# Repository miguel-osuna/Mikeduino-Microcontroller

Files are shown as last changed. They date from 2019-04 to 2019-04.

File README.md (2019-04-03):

# Mikeduino - My version of Arduino Uno R3
*"Mikeduino"* is a microcontroller board designed as a final project for the subject of Printed Circuits of the Electronics Engineering career.

## Purpose
It is based on the Open Source design of the *Arduino Uno R3* Microcontroller, but with the intention of improving the following aspects:

- Power signals
- Control signals
- Micro-USB port
- THT capacitor for improvement of power signal filtering

## Design 
The *Altium Designer 18* design software was used to create the following:

- Library of Components
- Bill Of Materials
- Schematic Diagram
- PCB design
- Generation of Documentation

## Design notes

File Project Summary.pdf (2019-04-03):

# Reporte de Proyecto Final

### Nombre del Circuito y Especificaciones Técnicas

### Alumno: Osuna Angulo Miguel Angel / 1237683 Nombre del Circuito: Mikeduino

Voltaje de operación | 5 V | SRAM | 2 KB
Voltaje de alimentación máximo: | 12 V | EEPROM | 1 KB
Pines Digitales de E/S | 14 | Velocidad de Reloj | 16 MHz
Pines Analógicos de Entrada | 6 | Largo (L) | 68.6 mm
Corriente máxima por pin (CD) | 40 mA | Ancho (W) | 54.5 mm
Memoria Flash | 32 KB ; para 0.5 KB bootloader | Peso | 25 g

### Tabla 1.- Especificaciones Técnicas del PCB

### Diagrama a Bloques

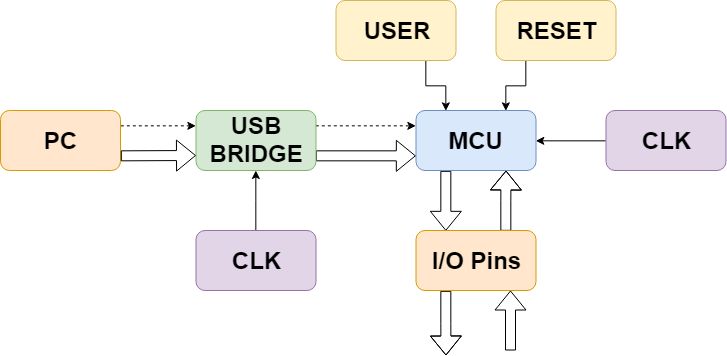
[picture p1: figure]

### Figura 1.- Diagrama a Bloques del Circuito

### Software EDA Utilizado

### Software: Altium 18.0 Licencia: Comercial Propietario

### Diagrama Esquemático

# Micro USB

JP2

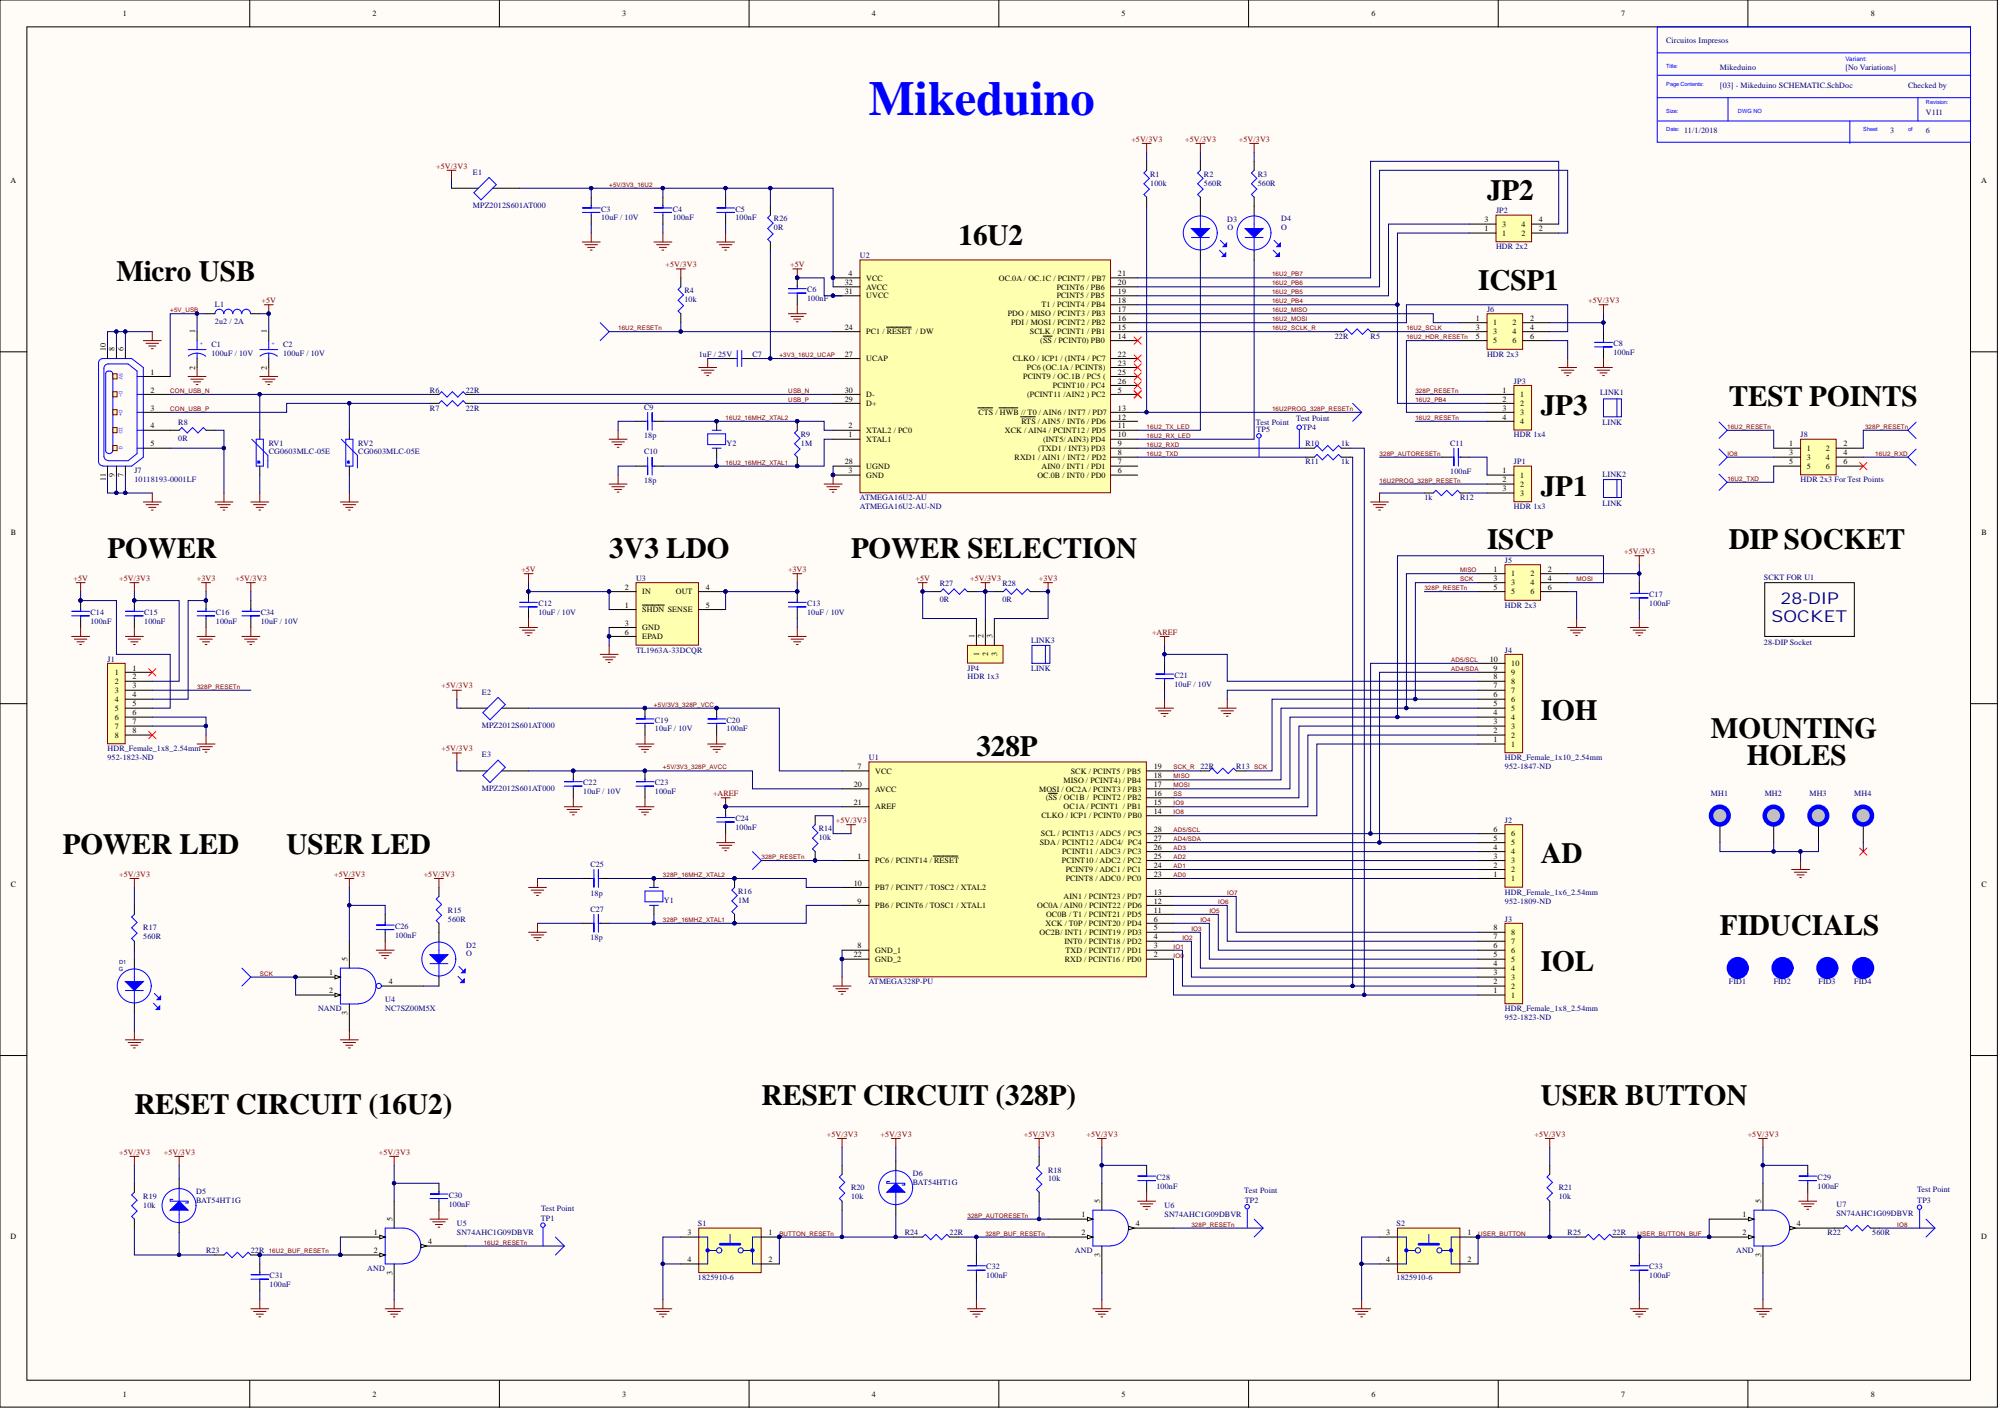
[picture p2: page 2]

HDR 2x3 For Test Points

### Simulación Eléctrica

- TP1: 16U2_RESETn (Salida del Circuito Reset del Microcontrolador 16U2) - TP2: 328P_RESETn (Salida del Circuito Reset del Microcontrolador 328P) - TP3: IO8 (Salida del Circuito de Botón de Usuario) - TP4: 16U2_RXD (Señal de Recepción del Microcontrolador 16U2) - TP5: 16U2_TXD (Señal de Transmisión del Microcontrolador 16U2)

### Oscilogramas Se muestra una idea de las señales que se pueden presentar en los puntos de prueba:

### - 16U2_RESETn

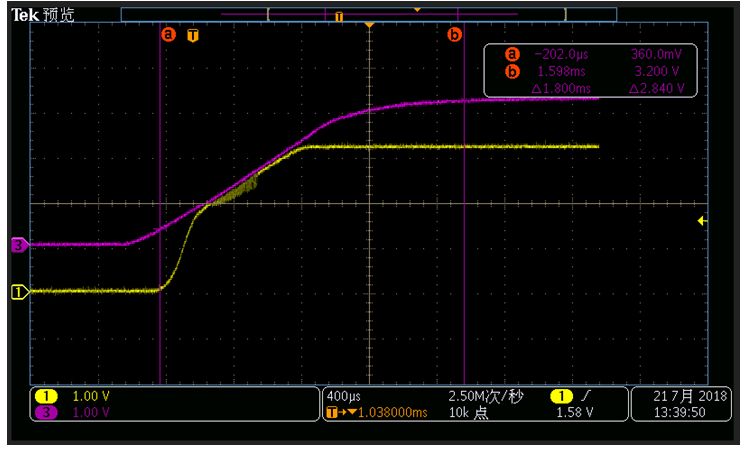
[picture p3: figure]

### Figura 2.- Ejemplo de señal de 16U2_RESETn

### - 328P_RESETn

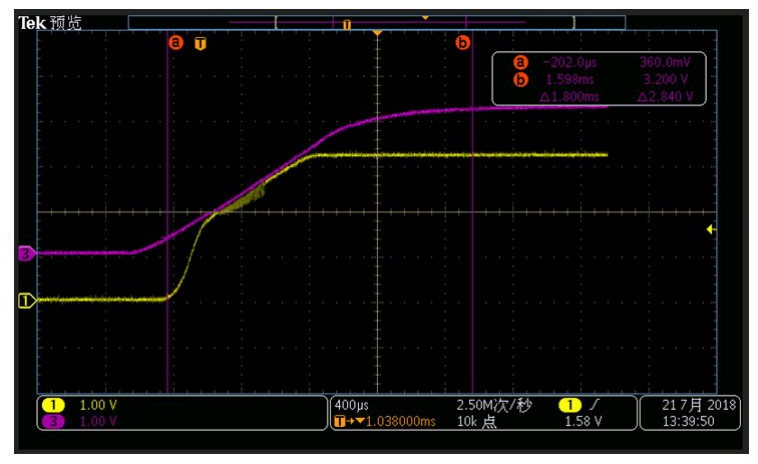
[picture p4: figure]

### Figura 3.- Ejemplo de señal de 328P_RESETn

- IO8

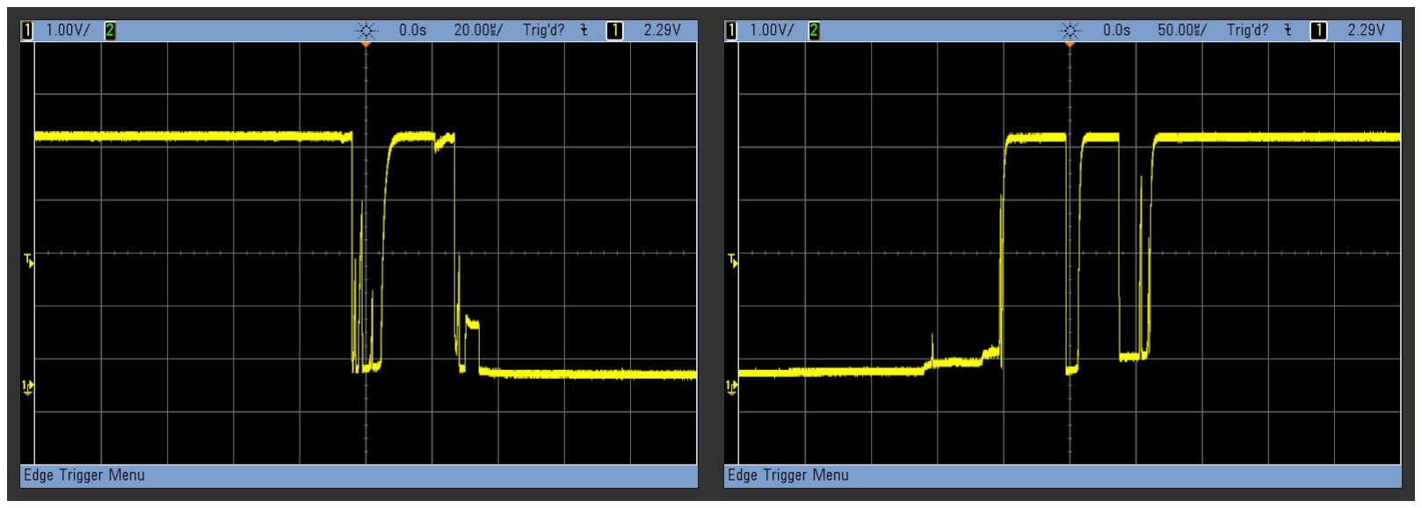
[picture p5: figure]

### Figura 4.- Ejemplo de señal de IO8

### - 16U2_RXD

### Figura 5.- Ejemplo de señal de 16U2_RXD

### - 16U2_TXD

### Figura 6.- Ejemplo de señal de 16U2_TXD

### Estimación del Área Total del PCB

Rubro | Componentes propuestos y tipo de PCB | Área de componentes ( mm ) 2 | Relación TS/CS esperada | Área del PCB ( mm ) 2
| Mezcla de componentes discretos e integrados (integrados entre el y el 35% 50% ). PCB tipo 1C. | 1363.239 | 2.0 a 3.0 | 2726.478 a 4089.717
Dimensiones deseadas para el PCB | 53.34 mm x 68.58 mm | - | - | 3, 58.0572 6

### Tabla 2.- Dimensiones y Estimación del Área Total del PCB

### Se estima que los componentes y el tipo de PCB propuesto tienen una gran

probabilidad de concordar con el PCB deseado.

# Micro USB

JP2

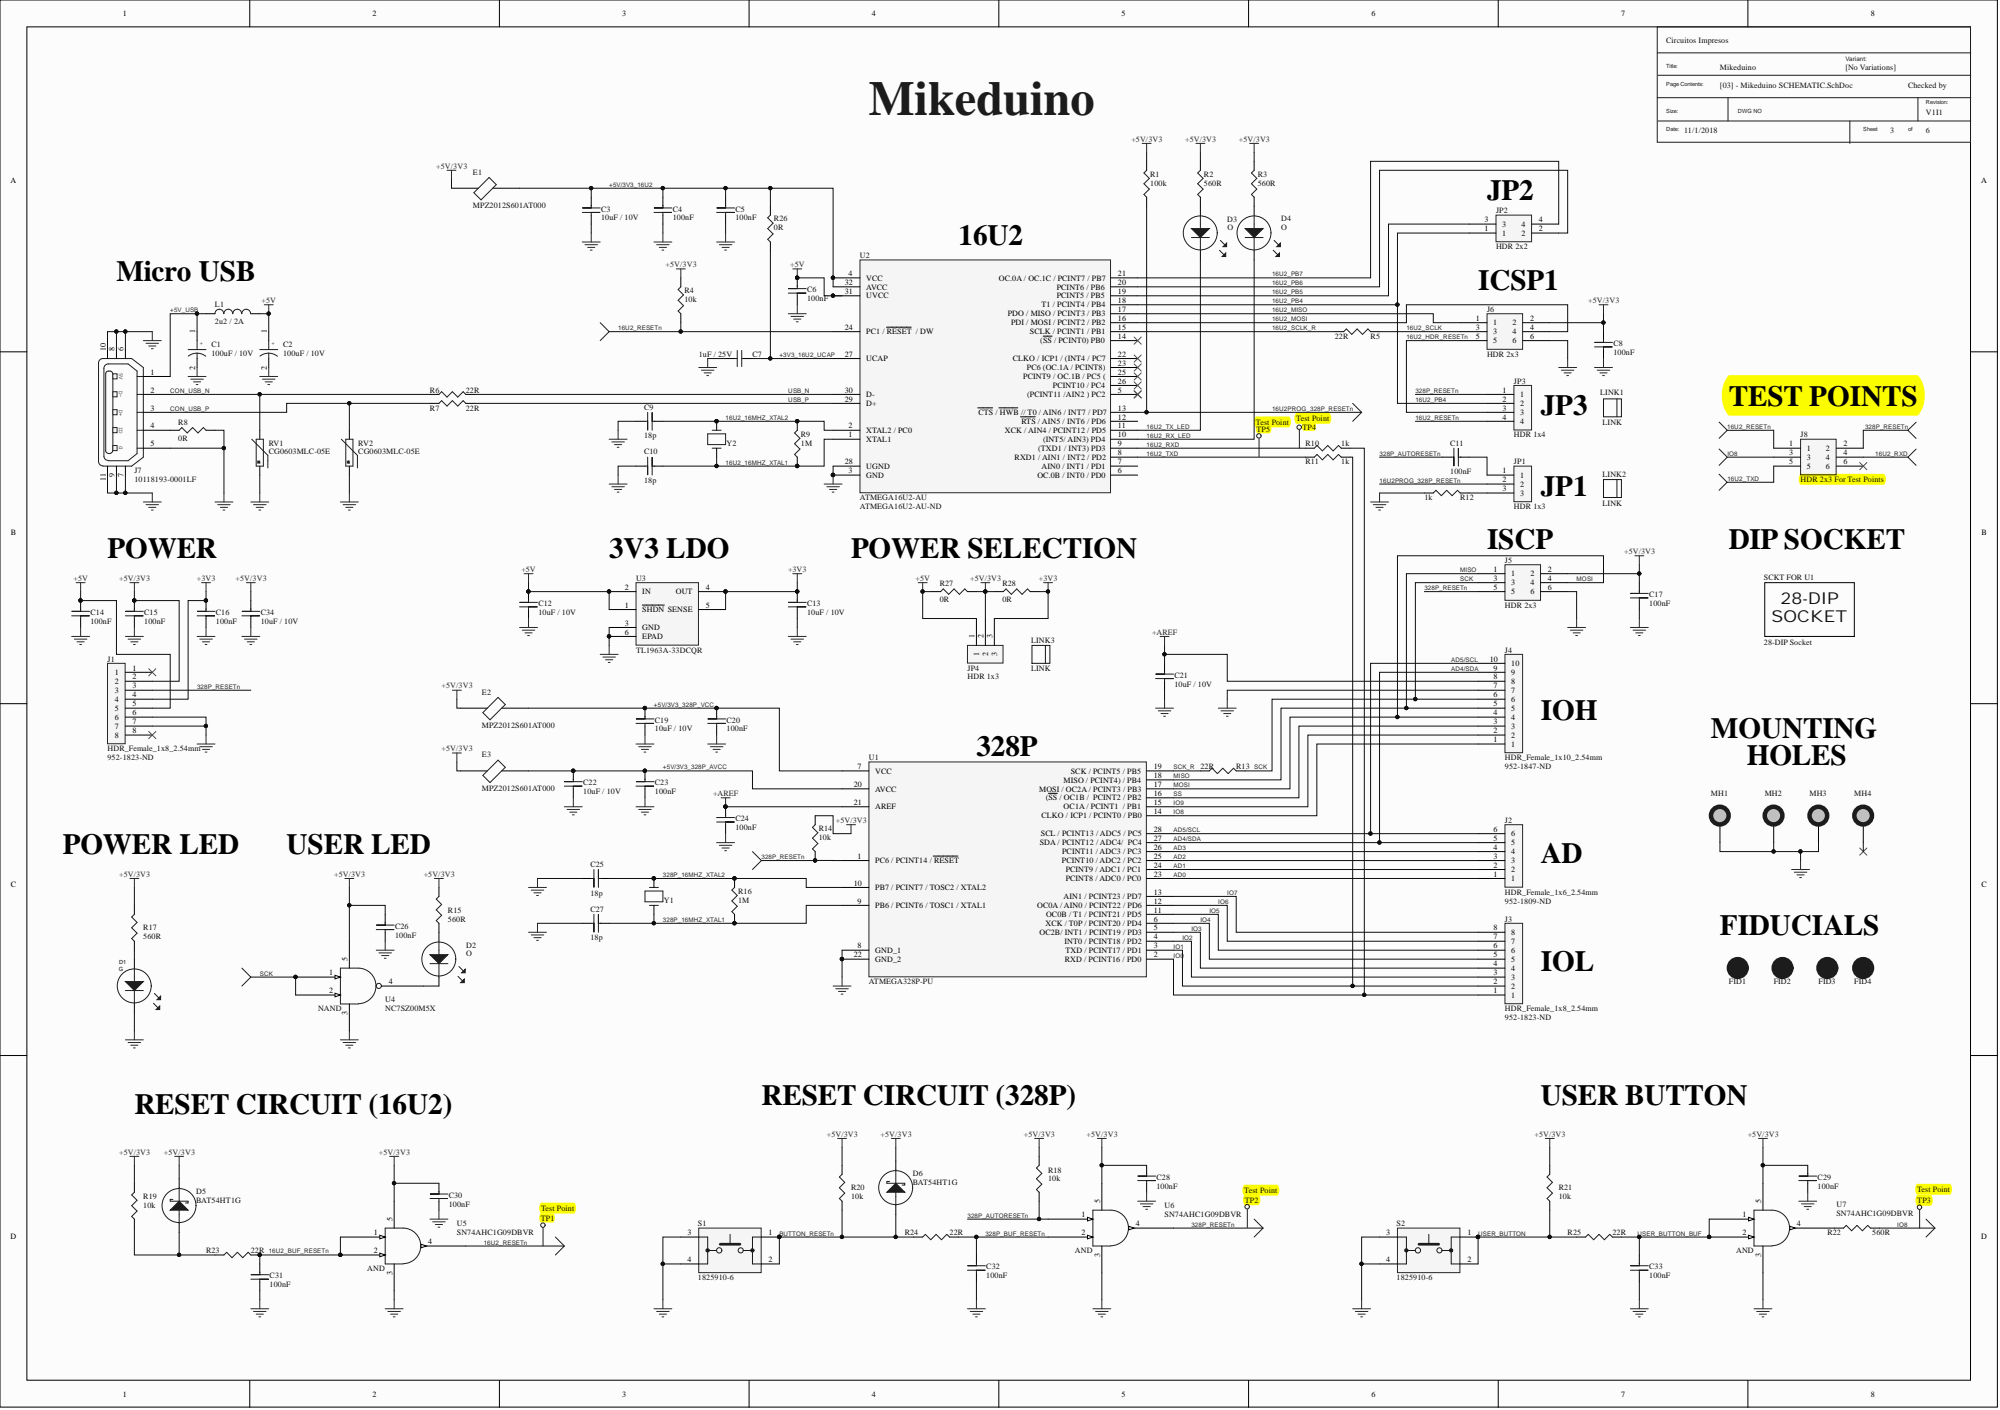
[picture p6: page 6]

HDR 2x3 For Test Points

# | Category | Desccription | Technology | Component

| | | | s | Length
| | | | | (mm) | Width
| | | | | | (mm) | Area
| | | | | | | (mm2) | Total Area
| | | | | | | | (mm2)
1 | Capacitors | CAP ALUM 100UF 20% 10V RADIAL | THT | 2 | 7 | 7 | 49 | 98
2 | Capacitors | Cap Ceramic 10uF 10V X5R 10% SMD 0805
| | 85C Cardboard T/R | SMD | 7 | 2 | 1.2 | 2.4 | 16.8
3 | Capacitors | CAP CER 0.1UF 50V X7R 0805 | SMD | 19 | 2 | 1.2 | 2.4 | 45.6
4 | Capacitors | CAP CER 1UF 25V 10% X5R 0805 | SMD | 1 | 2 | 1.2 | 2.4 | 2.4
5 | Capacitors | CAP CER 18PF 50V C0G/NP0 0805 | SMD | 4 | 2 | 1.2 | 2.4 | 9.6
6 | Optoelectronics | LED SMARTLED GREEN 570NM 0603 | SMD | 1 | 1.7 | 0.8 | 1.36 | 1.36
7 | Optoelectronics | LED ORANGE DIFFUSED 0603 SMD | SMD | 3 | 1.7 | 0.8 | 1.36 | 4.08
8 | Discrete Semiconductor Products | Diode Schottky 30V 200mA Surface Mount USC | SMD | 2 | 1.3 | 2.5 | 3.25 | 6.5
| | 0.1OHM, 2A, 0805, FULL REEL | SMD | 3 | 2 | 1.2 | 2.4 | 7.2
10 | Connectors, Interconnects | Headers & Wire Housings 8 PIN SIL VERTICAL SOCKET GOLD+TIN | THT | 2 | 20.72 | 2.45 | 50.764 | 101.528
| | SOCKET TIN | THT | 1 | 15.64 | 2.45 | 38.318 | 38.318
12 | Connectors, Interconnects | Headers & Wire Housings 10 PIN SIL VERTICAL SOCKET TIN | THT | 1 | 25.8 | 2.45 | 63.21 | 63.21
| | 6 Positions Header, Unshrouded Connector 0.100" (2.54mm) Through Hole Gold or Gold, GXT™ | THT | 3 | 7.62 | 5.05 | 38.481 | 115.443
14 | Connectors, Interconnects | CONN USB MICRO B RECPT SMT R/A | SMD | 1 | 8.2 | 6.1 | 50.02 | 50.02
9 | Coils | TDK MPZ2012S601AT000 FERRITE BEAD,
11 | Connectors, Interconnects | Headers & Wire Housings 6 PIN SIL VERTICAL
13 | Connectors, Interconnects
15 | Connectors, Interconnects | BERGSTIK II .100" SR STRAIGHT | THT | 2 | 7.25 | 2.45 | 17.7625 | 35.525
17 | Connectors, Interconnects | CONN HEADER 4POS .100 STR 15AU | THT | 1 | 9.8 | 2.45 | 24.01 | 24.01
18 | Inductors, Coils, Chokes | FIXED IND 2.2UH 2A 80 MOHM SMD | SMD | 1 | 3.2 | 2.5 | 8 | 8
19 | Connectors, Interconnects | CONN JUMPER SHORTING .100" GOLD | THT | 2 | 0 | 0 | 0 | 0
20 | Resistors | RES SMD 100K OHM 0.1% 1/8W 0805 | SMD | 1 | 2 | 1.2 | 2.4 | 2.4
21 | Resistors | RES SMD 560 OHM 1% 1/8W 0805 | SMD | 5 | 2 | 1.2 | 2.4 | 12
22 | Resistors | RES SMD 10K OHM 1% 1/8W 0805 | SMD | 6 | 2 | 1.2 | 2.4 | 14.4
23 | Resistors | RES SMD 22 OHM 1% 1/8W 0805 | SMD | 7 | 2 | 1.2 | 2.4 | 16.8
24 | Resistors | RES 0.0 OHM 1/8W 0805 SMD | SMD | 2 | 2 | 1.2 | 2.4 | 4.8
25 | Resistors | RES SMD 1M OHM 0.1% 1/8W 0805 | SMD | 2 | 2 | 1.2 | 2.4 | 4.8
26 | Resistors | RES SMD 1K OHM 1% 1/8W 0805 | SMD | 3 | 2 | 1.2 | 2.4 | 7.2
27 | Circuit Protection | VARISTOR 0603 | SMD | 2 | 1.7 | 0.8 | 1.36 | 2.72
28 | Switches | SWITCH TACTILE SPST-NO 0.05A 24V | SMD | 2 | 7.8 | 6 | 46.8 | 93.6
29 | Connectors, Interconnects | CONN IC DIP SOCKET 28POS TIN | THT | 1 | 10.1 | 35.55 | 359.055 | 359.055
30 | Microcontroller Unit | ATMEL ATMEGA328P-PU 8 Bit Microcontroller, Low Power High Performance, ATmega, 20 MHz, 32 KB, 2 KB, 28 Pins, DIP | THT | 1 | 0 | 0 | 0 | 0
| | 8BIT, MEGAAVR, 16MHZ, TQFP-32 | SMD | 1 | 10 | 10 | 100 | 100
32 | Integrated Circuits (ICs) | IC REG LDO 3.3V 1.5A SOT223-6 | SMD | 1 | 8.6 | 6.45 | 55.47 | 55.47
31 | Microcontroller Unit | ATMEL | ATMEGA16U2-AU | MCU,
33 | Integrated Circuits (ICs) | IC GATE NAND 1CH 2-INP SOT-23-5 | SMD | 1 | 3 | 1.7 | 5.1 | 5.1
34 | Integrated Circuits (ICs) | IC GATE AND SGL 2INP SOT23-5 | SMD | 3 | 3 | 1.7 | 5.1 | 15.3
35 | Crystals | Crystals 22.1184MHz 20ppm 18pF -40C+85C | SMD | 2 | 6 | 3.5 | 21 | 42
| | | TOTAL | 96 | 184.13 | 117.1 | 968.2205 | 1363.239

## Tabla 3.- Dimensiones de Componentes

## Dimensiones de Componentes

### Estimación del Área Total del PCB

Rubro | Componentes propuestos y tipo de PCB | Área de componentes ( mm ) 2 | Relación TS/CS esperada | Área del PCB ( mm ) 2
| Mezcla de componentes discretos e integrados (integrados entre el y el 35% 50% ). PCB tipo 1C. | 1363.239 | 2.0 a 3.0 | 2726.478 a 4089.717
Dimensiones deseadas para el PCB | 53.34 mm x 68.58 mm | - | - | 3, 58.0572 6

### Tabla 4.- Dimensiones y Estimación del Área Total del PCB

### Se estima que los componentes y el tipo de PCB propuesto tienen una gran

probabilidad de concordar con el PCB deseado.

# | Manufacturer Part | Manufacturer | Category | Reference | Description | Mount | Case / Package | Quantity

1 | EEA-GA1A101B | Panasonic | Capacitors | C1, C2 | CAP ALUM 100UF 20% 10V RADIAL | THT | Radial | 2
2 | CL21A106KPFNNNG | Samsung | Capacitors | C3, C12, C13, C19, C21, C22, C34 | Cap Ceramic 10uF 10V X5R 10% SMD 0805 85C Cardboard T/R | SMD | 0805 (2012 Metric) | 7
| | | | C4, C5, C6, C8, C11, C14, C15, C16, C17, C20, C23, C24, C26, C28, C29, C30, C31, C32, C33 | CAP CER 0.1UF 50V X7R 0805 | SMD | 0805 (2012 Metric) | 19
4 | C2012X5R1V105K085AB | TDK | Capacitors | C7 | CAP CER 1UF 35V X5R 0805 | SMD | 0805 (2012 Metric) | 1
3 | C2012X7R1H104M085AA | KEMET | Capacitors
5 | C0805C180J1GACTU | KEMET | Capacitors | C9, C10, C25, C27 | CAP CER 18PF 100V C0G/NP0 0805 | SMD | 0805 (2012 Metric) | 4
6 | LG L29K-G2J1-24-Z | Osram Opto | Optoelectronics | D1 | LED GREEN DIFFUSED 0603 SMD | SMD | 0603 (1608 Metric) | 1
7 | SML-E12D8WT86 | Rohm Semiconductor | Optoelectronics | D2, D3, D4 | LED ORANGE DIFFUSED 0603 SMD | SMD | 0603 (1608 Metric) | 3
8 | CUS520-H3F | Toshiba Semiconductor and Storage | Discrete Semiconductor Products | D5, D6 | Diode Schottky 30V 200mA Surface Mount USC | SMD | SC-76, SOD-323 | 2
9 | MPZ2012S601AT000 | TDK | Coils | E1, E2, E3 | TDK MPZ2012S601AT000 FERRITE BEAD, 0.1OHM, 2A, 0805, FULL REEL | SMD | 0805 (2012 Metric) | 3
10 | M20-7820842 | Harwin | Connectors, Interconnects | J1, J3 | Headers & Wire Housings 8 PIN SIL VERTICAL SOCKET GOLD+TIN | | | THT | SIP | 2
11 | M20-7820646 | Harwin | Connectors, Interconnects | J2 | Headers & Wire Housings 6 PIN SIL VERTICAL SOCKET TIN | | | THT | SIP | 1
12 | M20-7821046 | Harwin | Connectors, Interconnects | J4 | Headers & Wire Housings 10 PIN SIL VERTICAL SOCKET TIN | | | THT | SIP | 1
13 | 67997-206HLF | Amphenol FCI | Connectors, Interconnects | J5, J6, J8 | 6 Positions Header, Unshrouded Connector 0.100" (2.54mm) Through Hole Gold or Gold, GXT™ | THT | SIP | 3
14 | 10118193-0001LF | Amphenol FCI | Connectors, Interconnects | J7 | CONN USB MICRO B RECPT SMT R/A | SMD | USB Micro B | 1
15 | 68000-103HLF | Amphenol FCI | Connectors, Interconnects | JP1 | BERGSTIK II .100" SR STRAIGHT | THT | SIP | 2
17 | 68001-204HLF | Amphenol FCI | Connectors, Interconnects | JP3 | CONN HEADER 4POS .100 STR 15AU | THT | SIP | 1
18 | L1210R2R2MDWIT | KEMET | Inductors, Coils, Chokes | L1 | FIXED IND 2.2UH 2A 80 MOHM SMD | SMD | 1210 (3225 Metric) | 1
19 | QPC02SXGN-RC | Sullins | Connectors, Interconnects | LINK1, LINK2 | CONN JUMPER SHORTING .100" GOLD | THT | - | 2
20 | RC0805FR-07100KL | Panasonic | Resistors | R1 | RES SMD 100K OHM 0.1% 1/8W 0805 | SMD | 0805 (2012 Metric) | 1
21 | AC0805FR-07560RL | Yageo | Resistors | R2, R3, R15, R17, R22 | RES SMD 560 OHM 1% 1/8W 0805 | SMD | 0805 (2012 Metric) | 5
22 | RC0805FR-0710KL | Yageo | Resistors | R4, R14, R18, R19, R20, R21 | RES SMD 10K OHM 1% 1/8W 0805 | SMD | 0805 (2012 Metric) | 6
23 | RC0805FR-0722RL | Yageo | Resistors | R5, R6, R7, R13, R23, R24, R25 | RES SMD 22 OHM 1% 1/8W 0805 | SMD | 0805 (2012 Metric) | 7
24 | CR0805-J/-000ELF | Bourns Inc. | Resistors | R8, R27 | RES SMD 0 OHM JUMPER 1/8W 0805 | SMD | 0805 (2012 Metric) | 2
25 | ERA-6AEB105V | Panasonic | Resistors | R9, R16 | RES SMD 1M OHM 0.1% 1/8W 0805 | SMD | 0805 (2012 Metric) | 2
26 | RC0805FR-071KL | Yageo | Resistors | R10, R11, R12 | RES SMD 1K OHM 1% 1/8W 0805 | SMD | 0805 (2012 Metric) | 3
27 | CG0603MLC-05E | Bourns | Circuit Protection | RV1, RV2 | VARISTOR 0603 | SMD | 0603 (1608 Metric) | 2
28 | 1825910-6 | TE Connectivity Alcoswitch | Switches | S1, S2 | SWITCH TACTILE SPST-NO 0.05A 24V | SMD | - | 2
29 | 4828-3004-CP | 3M | Connectors, Interconnects | SCKT FOR U1 | CONN IC DIP SOCKET 28POS TIN | THT | DIP | 1
30 | ATMEGA328P-PU | Microchip | Microcontroller Unit | U1
ATMEL | ATMEGA328P-PU | 8 Bit
Microcontroller, Low Power High Performance, ATmega, 20 MHz, 32 KB, 2 KB, 28 Pins, DIP
| | | | | | | | THT | DIP | 1
31 | ATMEGA16U2-AU | Microchip | Microcontroller Unit | U2 | ATMEL | ATMEGA16U2-AU | MCU, 8BIT, MEGAAVR, 16MHZ, TQFP-32 | SMD | QFN | 1
32 | TL1963A-33DCQR | Texas Instruments | Integrated Circuits (ICs) | U3 | IC REG LDO 3.3V 1.5A SOT223-6 | SMD | SOT-223-6 | 1
33 | NC7SZ00M5X | ON Semiconductor / Fairchild | Integrated Circuits (ICs) | U4 | IC GATE NAND 1CH 2-INP SOT-23-5 | SMD | SC-74A, SOT-753 | 1
34 | SN74AHC1G09DBVR | Texas Instruments | Integrated Circuits (ICs) | U5, U6, U7 | IC GATE AND SGL 2INP SOT23-5 | SMD | SC-74A, SOT-753 | 3
35 | ABM7-22.1184MHZ-D2Y- T | Abracon | Crystals | Y1, Y2 | Crystals 22.1184MHz 20ppm 18pF -40C+85C | SMD | CSMD | 2
| | | | | | | | | TOTAL | 96

## Tabla 5.- Lista de Materiales

## Lista de Materiales

### Diseño del PCB

Parámetro | Descripción
Espaciado entre Componentes | Los componentes están espaciados con un mínimo de ; 0.2 mm esto fue implementado como regla de diseño para poder facilitar el ensamble de componentes.
Elección del Número de Caras | En este caso, el PCB cuenta con dos caras.
Elección del Sustrato | El PCB contiene un sustrato FR-4: fibra de vidrio + resina epóxica + retardante de llama.
Elección del Tipo y Espesor del Conductor | Conductor: Cobre Espesor del Conductor: ft² oz lo que es equivalente a 35 mm de 1 espesor.
Espesor del Laminado | Se utiliza un espesor de laminado de . Este espesor se 1.6 mm podría encontrar entre L13 y L14 del IPC (1.5 y 1.9 respectivamente).
Elección de las Formas de los Pads | Para el diseño del circuito, se utilizaron Pads con forma rectangular, circular y ovalada, para componentes de THT y Pads con forma rectangular para SMT.

### Tabla 6.- Parámetros de Diseño del PCB

### Elementos Parásitos del PCB

### El cálculo de todos los parámetros fue realizado tomando en cuenta el peor de los

casos; esto se incluye en variables.

Elemento | Variables | Método Utilizado | Resultado
Resistencia (Línea de Señal) | Imax = 1 A , V p = 5 V dT = 10°C , oz , t = 1 ft² Tamb = 25°C , L = 144 mm | Calculadora para PCB: https://www.4pcb.com/trace-w idth-calculator.html | R = 0.243 Ω
Resistencia (Línea de Alimentación) | Imax = 1 A , V p = 5 V oz dT = 10°C , , t = 1 ft² Tamb = 25°C , L = 119.997 mm | Calculadora para PCB: https://www.4pcb.com/trace-w idth-calculator.html | R = 0.202 Ω
Capacitancia Parásita Adyacente | ε = 3.5x10 −12 F , t = 1 ft² = 3 oz 5 μm m , L = 144.634 mm , d = 0.2 mm | Cálculo por la geometría del PCB | Ca = 0.08858 pF
Capacitancia | −12 ε = 4.8x10 F , t = 0.31 mm , m | Cálculo por la geometría del | Cs = 0.1345 pF

Parásita Colindante | L = 144.634 mm , d = 1.6 mm | PCB
Inductancia Parásita | W = 0.31 mm , L = 144.634 mm , H = 1.6 mm | Calculadora para PCB: | L = 0.00160 μH

### Tabla 7.- Elementos Parásitos del PCB

### Distribución de Componentes

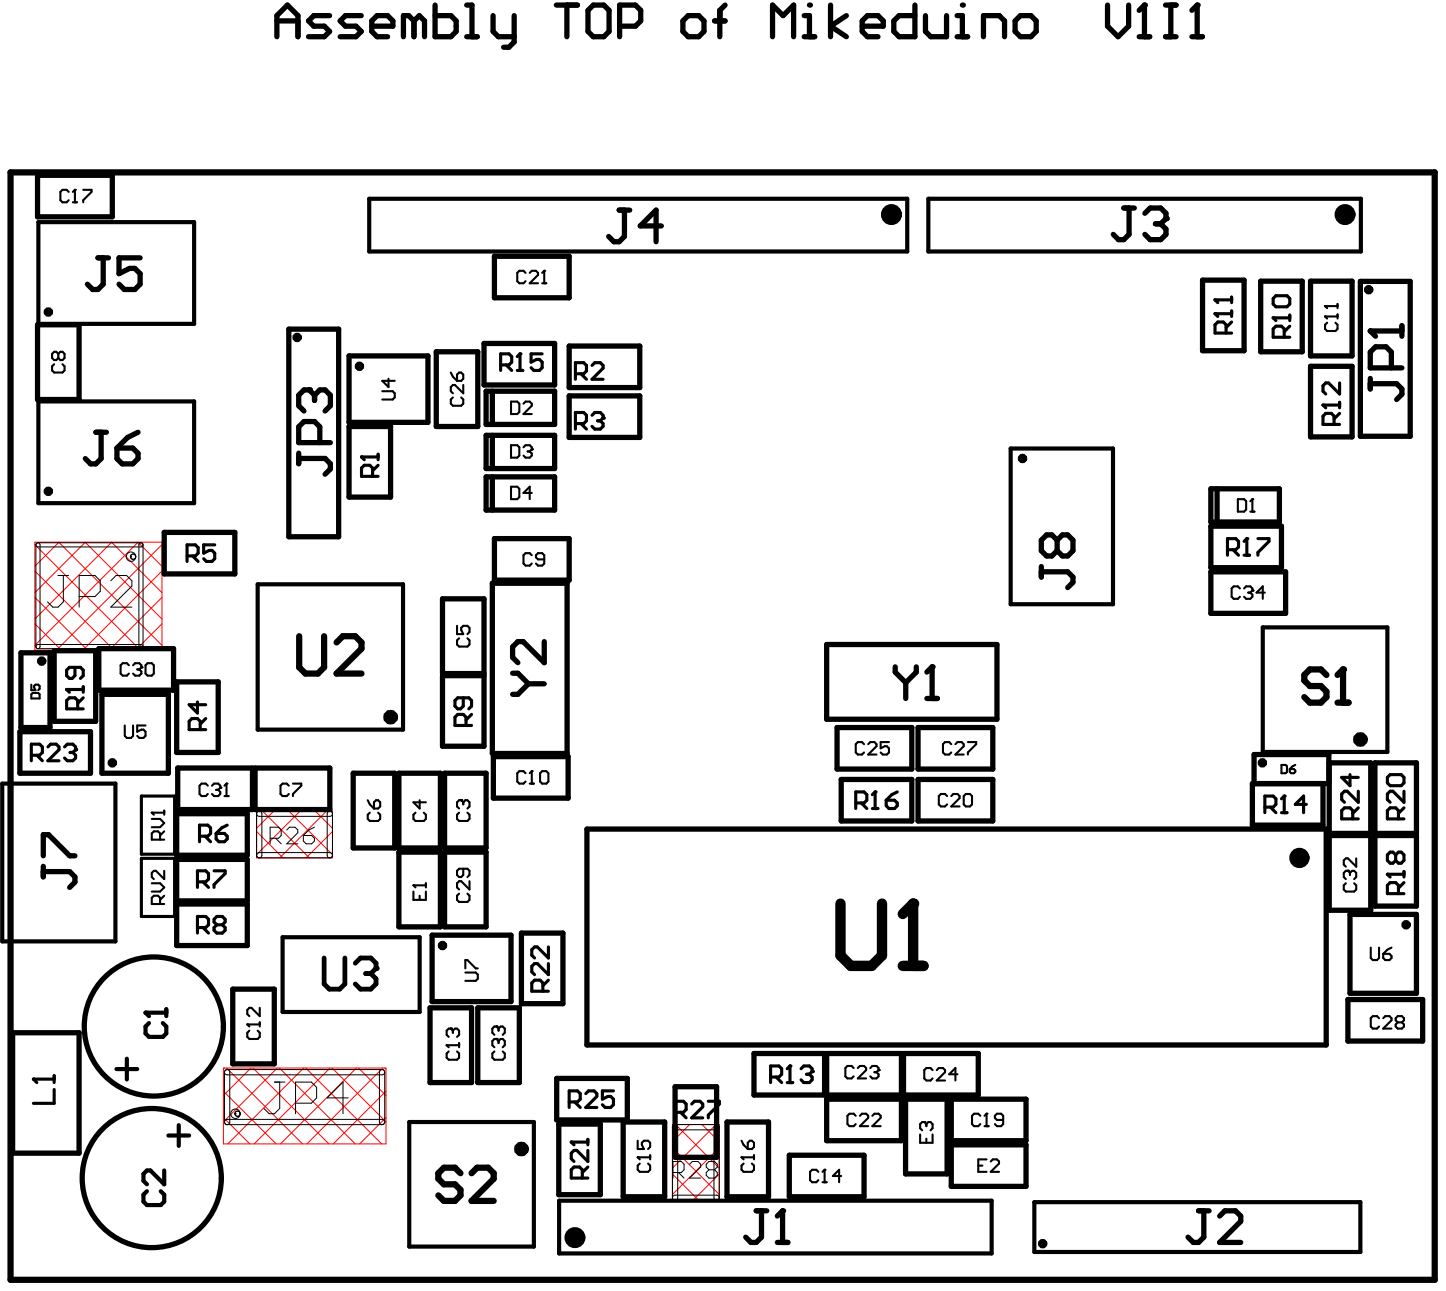
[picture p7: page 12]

## Máscara de Soldadura Superior

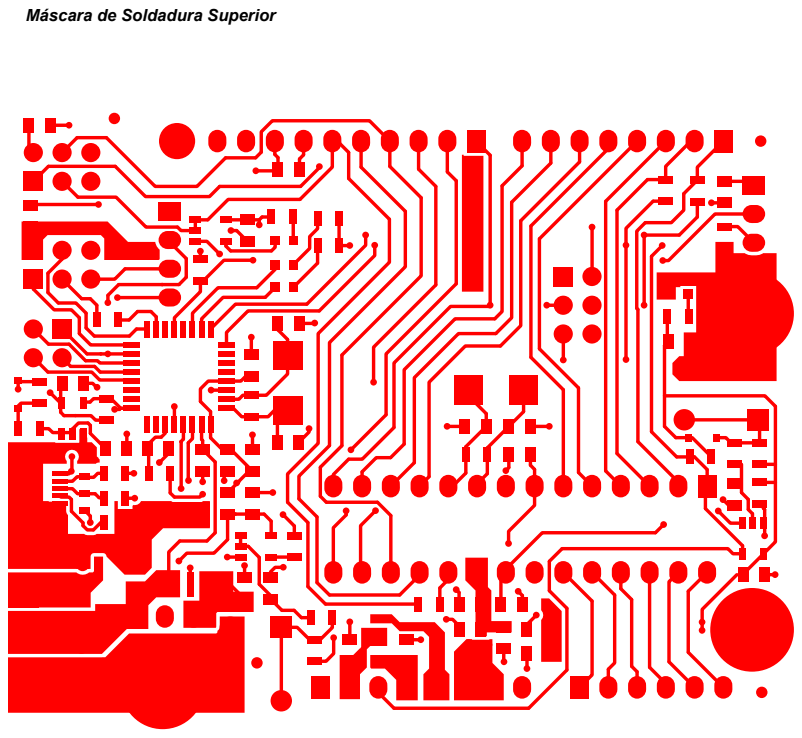
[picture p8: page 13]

## Máscara de Soldadura Inferior

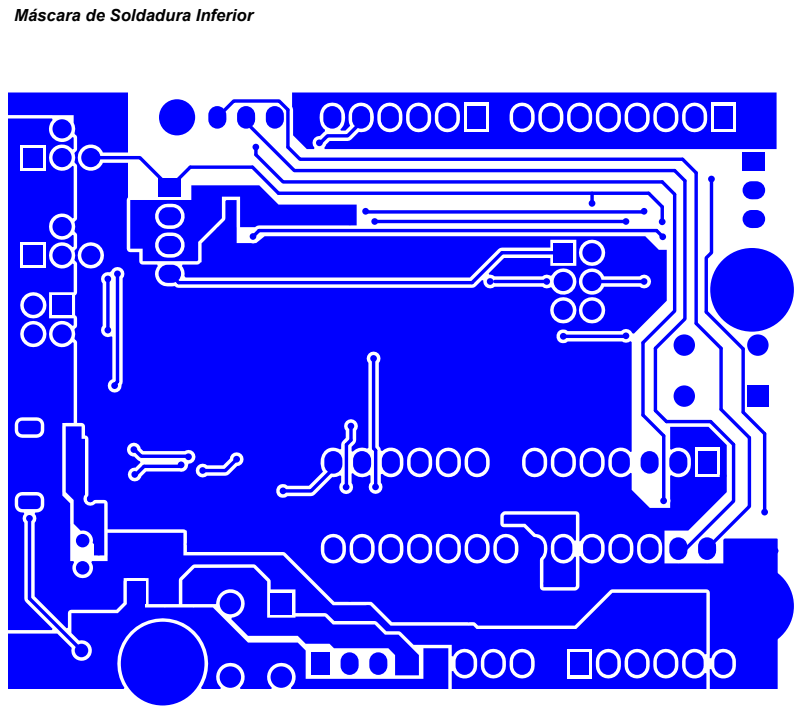
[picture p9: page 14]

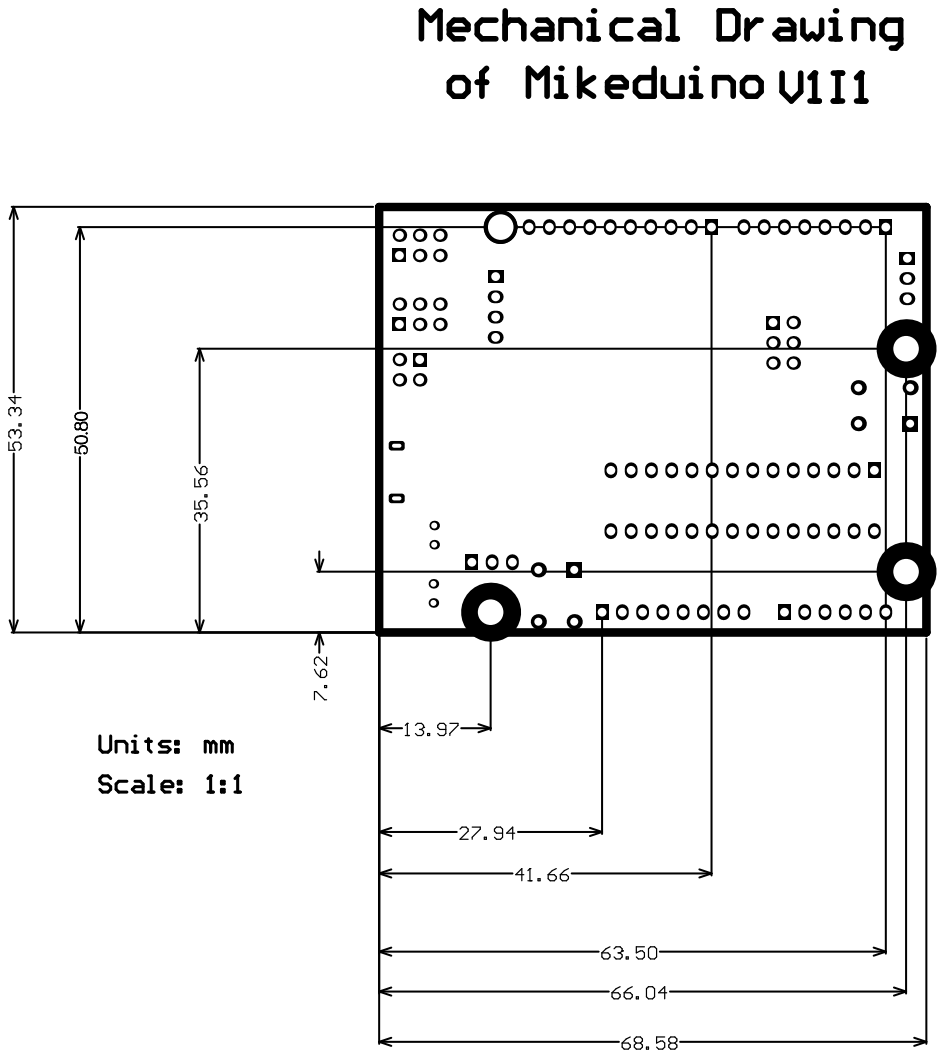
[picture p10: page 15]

## Máscara de Antisoldadura Superior

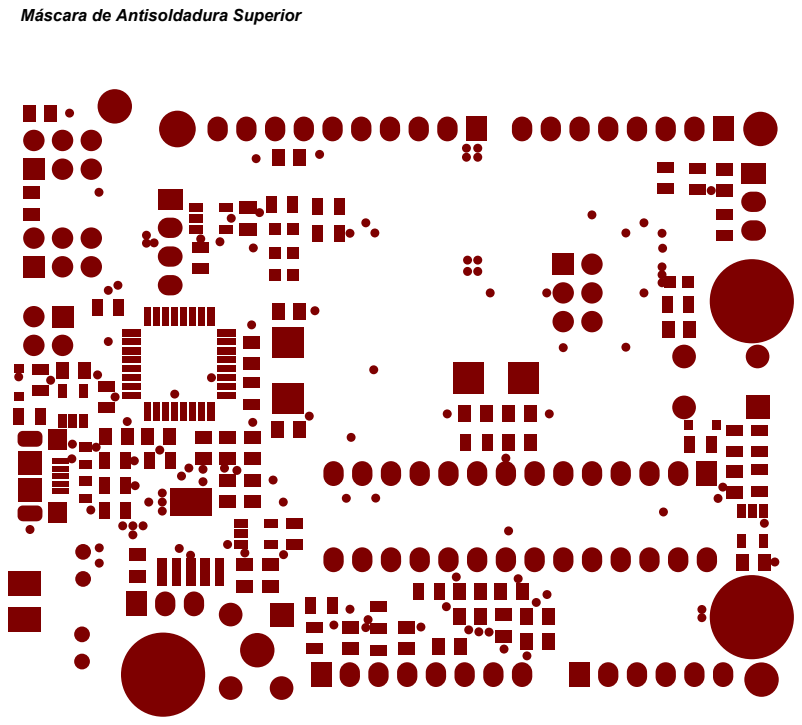
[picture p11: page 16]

## Máscara de Antisoldadura Inferior

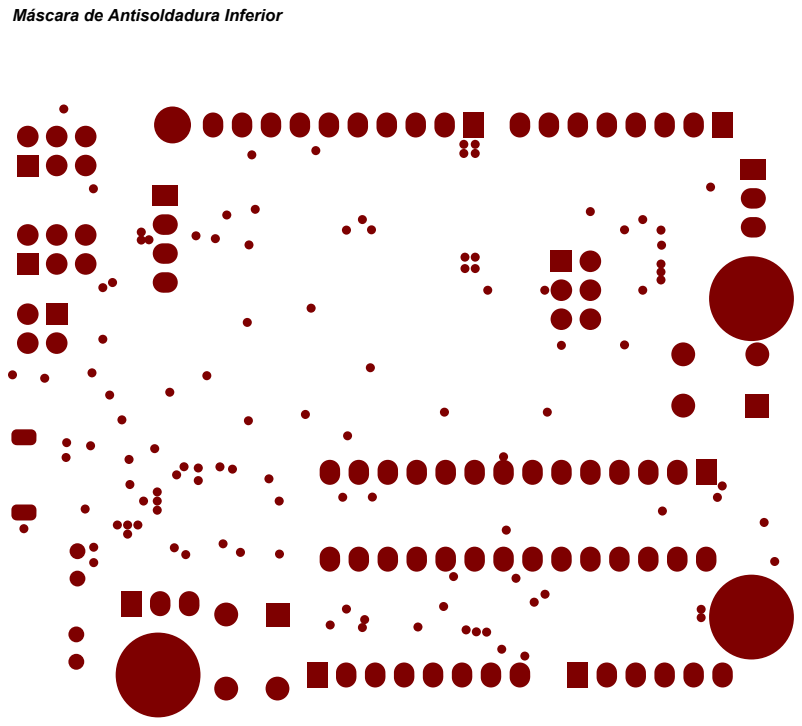
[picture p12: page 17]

## Máscara de Leyendas Superior

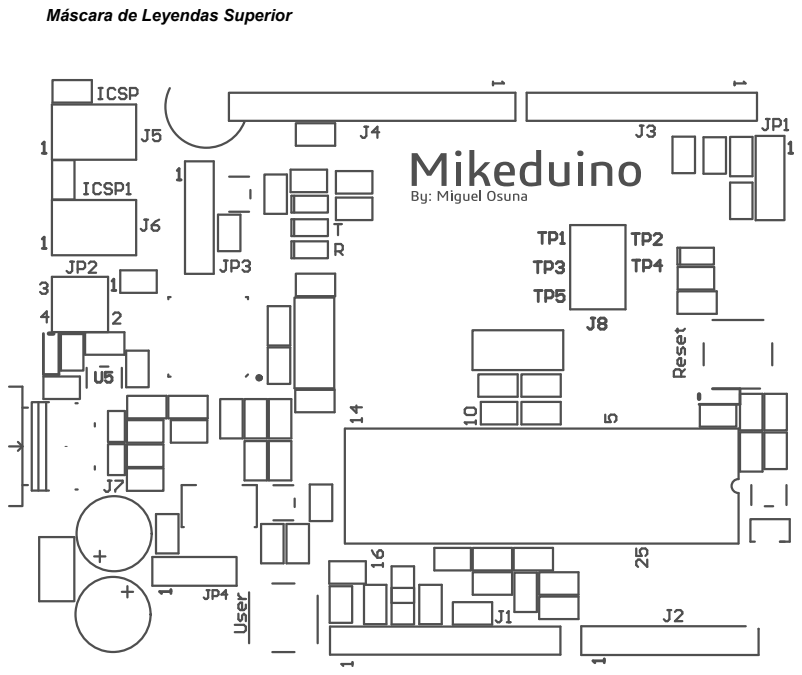
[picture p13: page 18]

## Máscara de Leyendas Inferior

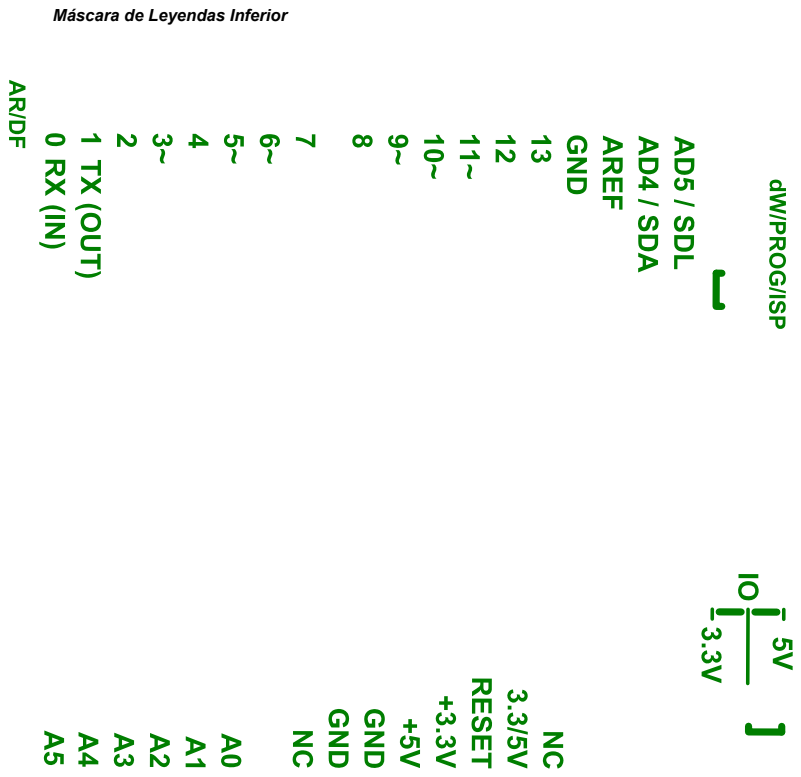
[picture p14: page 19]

### Modo y Capacidades de Fabricación del Manufacturero La fabricación del circuito impreso fue hecho por la empresa JLCPCB (https://jlcpcb.com/quote), y con las siguientes especificaciones:

Parámetro de Fabricación | Resultado
Layers | 2 Capas
Producción mínima | 10 piezas
Color de antisoldadura | Verde
Terminado de superficie | HASL (con plomo)
Material utilizado | Tarjeta de FR-4
Dimensiones de tarjeta | 53.34 mm x 68.58 mm
Tolerancia de contorno | ± 0.2 mm
Máscara de antisoldadura | LPI (Liquid Photo-Imageable Solder)
Espesor de la tarjeta | 1.6 mm
Ancho del espesor | ± 10%
Espesor del conductor en capa exterior | 1 oz 2 ó 35 μm ft
Espesor del conductor en capa interior | 0.5 oz ó 17 μm
Ancho mínimo de pista | 3.5 mil
Distancia de separación mínima entre pistas | 3.5 mil
Tamaño mínimo del orificio de la vía | 0.2 mil
Diámetro mínimo de la vía | 0.45 mil
Distancia de separación mínima entre via y pista | ≥ 5 mil
Tamaño de orificios | 0.2 − 6.3 mm
Tolerancia del tamaño del orificio | ± 0.08 mm
Anillo anular | ≥ 3 mil
Ancho mínimo de caracteres | ≥ 6 mil
Altura mínima de caracteres | ≥ 32 mil
Distancia de pista a contorno | ≥ 0.2 mil

### Tabla 8.- Parámetros de Fabricación de la Empresa

### Formato Solicitado por el Manufacturero

### Se solicitaron los siguientes archivos gerber para la creación del PCB:

- boardname.GTL: Máscara Superior - boardname.GBL: Máscara Inferior - boardname.GTS: Máscara Anti-Soldadura Superior - boardname.GBS: Máscara Anti-Soldadura Inferior - boardname.GTO: Máscara de Leyendas Superior - boardname.GBO: Máscara de Leyendas Inferior - boardname.GKO: Contorno de la Tarjeta - boardname.G2L: Sólo si se está creando una tercera capa - boardname.XLN: Máscara de Taladro

### Pruebas Eléctricas Sin Componentes

Elemento | Resultado
Resistencia Máxima entre Nodos | 0.28 Ω
Aislamiento Mínimo entre Pistas | 0.2 mm
Capacitancia Máxima de Pista | 0.021 nF
Inductancia Máxima de Pista | 0.0015 μH

### Tabla 9.- Resultados de pruebas eléctricas a PCB sin componentes

### Pruebas Eléctricas Con Componentes

Elemento | Resultado
Resistencia Máxima entre Nodos | 0.3 Ω
Aislamiento Mínimo entre Pistas | 0.2 mm
Capacitancia Máxima de Pista | 0.025 nF
Inductancia Máxima de Pista | 0.0018 μH

### Tabla 10.- Resultados de pruebas eléctricas a PCB con componentes

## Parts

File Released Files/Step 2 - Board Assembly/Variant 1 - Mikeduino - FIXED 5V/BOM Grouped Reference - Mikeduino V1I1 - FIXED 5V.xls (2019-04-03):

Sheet: Part List Report
 | Component reference list (grouped) |  |  |  | Mikeduino
 | Source Data From: |  | Mikeduino.PrjPcb |  |  | Contact: |  | Generated by:
 | Project: |  | Mikeduino.PrjPcb
 | Variant: |  | FIXED 5V |  |  |  |  | FEDEVEL
 | Report Date: |  | 10/20/2018 | 1:34:42 AM |  |  |  | http://www.fedevel.com
 | Print Date: |  | 2018-10-20 | 1:34:51
# | Designator | Quantity | Comment | Description | Manufacturer 1 | Manufacturer Part Number 1 | Package / Case | Supplier 1 | Supplier Part Number 1
1 | C1, C2 | 2 | 100uF / 10V | CAP ALUM 100UF 20% 10V RADIAL | Panasonic (https://octopart-clicks.com/click/altium?sku=P15782CT-ND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) | EEA-GA1A101B (https://octopart-clicks.com/click/altium?sku=P15782CT-ND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) |  | Digi-Key | P15782CT-ND (https://octopart-clicks.com/click/altium?sku=P15782CT-ND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)
2 | C3, C12, C13, C19, C21, C22, C34 | 7 | 10uF / 10V | Cap Ceramic 10uF 10V X5R 10% SMD 0805 85C Cardboard T/R | Samsung (https://octopart-clicks.com/click/altium?sku=1276-2402-6-ND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) | CL21A106KPCLQNC (https://octopart-clicks.com/click/altium?sku=1276-2402-6-ND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) |  | Digi-Key | 1276-2402-6-ND (https://octopart-clicks.com/click/altium?sku=1276-2402-6-ND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)
3 | C4, C5, C6, C8, C11, C14, C15, C16, C17, C20, C23, C24, C26, C28, C29, C30, C31, C32, C33 | 19 | 100nF | TDK CEU4J2X7R1H104K125AE SMD Multilayer Ceramic Capacitor, 0805 [2012 Metric], 0.1 F, 50 V, 10%, X7R, CEU Series | TDK (https://octopart-clicks.com/click/altium?sku=445-7856-2-ND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) | CEU4J2X7R1H104K125AE (https://octopart-clicks.com/click/altium?sku=445-7856-2-ND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) |  | Digi-Key | 445-7856-2-ND (https://octopart-clicks.com/click/altium?sku=445-7856-2-ND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)
4 | C7 | 1 | 1uF / 25V | CAP CER 1UF 25V 10% X5R 0805 | TDK (https://octopart-clicks.com/click/altium?sku=445-1419-1-ND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) | C2012X5R1E105K125AA (https://octopart-clicks.com/click/altium?sku=445-1419-1-ND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) | 0805 (2012 Metric) | Digi-Key | 445-1419-1-ND (https://octopart-clicks.com/click/altium?sku=445-1419-1-ND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)
5 | C9, C10, C25, C27 | 4 | 18p | KEMET 18pF Multilayer Ceramic Capacitor (MLCC) 50 V dc 5% C0G dielectric C SMD max op. temp. +125C | KEMET (https://octopart-clicks.com/click/altium?sku=399-1112-6-ND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) | C0805C180J5GAC-TU (https://octopart-clicks.com/click/altium?sku=399-1112-6-ND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) |  | Digi-Key | 399-1112-6-ND (https://octopart-clicks.com/click/altium?sku=399-1112-6-ND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)
6 | D1 | 1 | G | LED SMARTLED GREEN 570NM 0603 | Osram Opto (https://octopart-clicks.com/click/altium?sku=475-2709-1-ND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) | Q65110A1746 (https://octopart-clicks.com/click/altium?sku=475-2709-1-ND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) | 0603 (1608 Metric) | Digi-Key | 475-2709-1-ND (https://octopart-clicks.com/click/altium?sku=475-2709-1-ND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)
7 | D2, D3, D4 | 3 | O | LED SMARTLED ORANGE 606NM 0603 | Osram Opto (https://octopart-clicks.com/click/altium?sku=475-2740-1-ND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) | LOL29K-H2K1-24-Z (https://octopart-clicks.com/click/altium?sku=475-2740-1-ND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) | 0603 (1608 Metric) | Digi-Key | 475-2740-1-ND (https://octopart-clicks.com/click/altium?sku=475-2740-1-ND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)
8 | D5, D6 | 2 | BAT54HT1G | DIODE SCHOTTKY 30V 0.2A SOD323 | ON Semiconductor / Fairchild (https://octopart-clicks.com/click/altium?manufacturer=ON%20Semiconductor%20%2F%20Fairchild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) | BAT54HT1G (https://octopart-clicks.com/click/altium?manufacturer=ON%20Semiconductor%20%2F%20Fairchild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) | SC-76, SOD-323 | Digi-Key | BAT54HT1GCT-ND (https://octopart-clicks.com/click/altium?manufacturer=ON%20Semiconductor%20%2F%20Fairchild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)
9 | E1, E2, E3 | 3 | MPZ2012S601AT000 | TDK MPZ2012S601AT000 FERRITE BEAD, 0.1OHM, 2A, 0805, FULL REEL | TDK (https://octopart-clicks.com/click/altium?sku=445-2206-6-ND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) | MPZ2012S601AT000 (https://octopart-clicks.com/click/altium?sku=445-2206-6-ND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) |  | Digi-Key | 445-2206-6-ND (https://octopart-clicks.com/click/altium?sku=445-2206-6-ND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)
10 | J1, J3 | 2 | HDR_Female_1x8_2.54mm | Headers & Wire Housings 8 PIN SIL VERTICAL SOCKET GOLD+TIN | Harwin (https://octopart-clicks.com/click/altium?sku=952-1823-ND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) | M20-7820842 (https://octopart-clicks.com/click/altium?sku=952-1823-ND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) |  | Digi-Key | 952-1823-ND (https://octopart-clicks.com/click/altium?sku=952-1823-ND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)
11 | J2 | 1 | HDR_Female_1x6_2.54mm | Headers & Wire Housings 6 PIN SIL VERTICAL SOCKET TIN | Harwin (https://octopart-clicks.com/click/altium?sku=952-1809-ND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) | M20-7820646 (https://octopart-clicks.com/click/altium?sku=952-1809-ND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) |  | Digi-Key | 952-1809-ND (https://octopart-clicks.com/click/altium?sku=952-1809-ND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)
12 | J4 | 1 | HDR_Female_1x10_2.54mm | Headers & Wire Housings 10 PIN SIL VERTICAL SOCKET TIN | Harwin (https://octopart-clicks.com/click/altium?sku=952-1847-ND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) | M20-7821046 (https://octopart-clicks.com/click/altium?sku=952-1847-ND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) |  | Digi-Key | 952-1847-ND (https://octopart-clicks.com/click/altium?sku=952-1847-ND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)
13 | J5, J6 | 2 | HDR 2x3 | 6 Positions Header, Unshrouded Connector 0.100" (2.54mm) Through Hole Gold or Gold, GXT™ | Amphenol FCI (https://octopart-clicks.com/click/altium?sku=609-3234-ND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) | 67997-206HLF (https://octopart-clicks.com/click/altium?sku=609-3234-ND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) |  | Digi-Key | 609-3234-ND (https://octopart-clicks.com/click/altium?sku=609-3234-ND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)
14 | J7 | 1 | 10118193-0001LF | CONN USB MICRO B RECPT SMT R/A | Amphenol FCI (https://octopart-clicks.com/click/altium?sku=609-4616-1-ND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) | 10118193-0001LF (https://octopart-clicks.com/click/altium?sku=609-4616-1-ND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) |  | Digi-Key | 609-4616-1-ND (https://octopart-clicks.com/click/altium?sku=609-4616-1-ND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)
15 | J8 | 1 | HDR 2x3 For Test Points | 6 Positions Header, Unshrouded Connector 0.100" (2.54mm) Through Hole Gold or Gold, GXT™ | Amphenol FCI (https://octopart-clicks.com/click/altium?sku=609-3234-ND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) | 67997-206HLF (https://octopart-clicks.com/click/altium?sku=609-3234-ND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) |  | Digi-Key | 609-3234-ND (https://octopart-clicks.com/click/altium?sku=609-3234-ND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)
16 | JP1 | 1 | HDR 1x3 | BERGSTIK II .100" SR STRAIGHT | Amphenol FCI (https://octopart-clicks.com/click/altium?sku=609-3461-ND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) | 68000-103HLF (https://octopart-clicks.com/click/altium?sku=609-3461-ND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) |  | Digi-Key | 609-3461-ND (https://octopart-clicks.com/click/altium?sku=609-3461-ND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)
17 | JP3 | 1 | HDR 1x4 | CONN HEADER 4POS .100 STR 15AU | Amphenol FCI (https://octopart-clicks.com/click/altium?sku=609-3402-ND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) | 68001-204HLF (https://octopart-clicks.com/click/altium?sku=609-3402-ND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) |  | Digi-Key | 609-3402-ND (https://octopart-clicks.com/click/altium?sku=609-3402-ND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)
18 | L1 | 1 | 2u2 / 2A | FIXED IND 2.2UH 2A 80 MOHM SMD | KEMET (https://octopart-clicks.com/click/altium?sku=399-9598-1-ND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) | L1210R2R2MDWIT (https://octopart-clicks.com/click/altium?sku=399-9598-1-ND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) | 1210 (3225 Metric) | Digi-Key | 399-9598-1-ND (https://octopart-clicks.com/click/altium?sku=399-9598-1-ND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)
19 | LINK1, LINK2 | 2 | LINK | CONN JUMPER SHORTING .100" GOLD | Sullins (https://octopart-clicks.com/click/altium?sku=S9337-ND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) | QPC02SXGN-RC (https://octopart-clicks.com/click/altium?sku=S9337-ND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) |  | Digi-Key | S9337-ND (https://octopart-clicks.com/click/altium?sku=S9337-ND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)
20 | R1 | 1 | 100k | RES SMD 100K OHM 1% 1/8W 0805 | Yageo (https://octopart-clicks.com/click/altium?sku=311-100KCRCT-ND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) | RC0805FR-07100KL (https://octopart-clicks.com/click/altium?sku=311-100KCRCT-ND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) | 0805 (2012 Metric) | Digi-Key | 311-100KCRCT-ND (https://octopart-clicks.com/click/altium?sku=311-100KCRCT-ND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)
21 | R2, R3, R15, R17, R22 | 5 | 560R | RES SMD 560 OHM 1% 1/8W 0805 | Yageo (https://octopart-clicks.com/click/altium?sku=311-560CRCT-ND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) | RC0805FR-07560RL (https://octopart-clicks.com/click/altium?sku=311-560CRCT-ND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) | 0805 (2012 Metric) | Digi-Key | 311-560CRCT-ND (https://octopart-clicks.com/click/altium?sku=311-560CRCT-ND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)
22 | R4, R14, R18, R19, R20, R21 | 6 | 10k | RES SMD 10K OHM 1% 1/8W 0805 | Yageo (https://octopart-clicks.com/click/altium?sku=311-10.0KCRCT-ND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) | RC0805FR-0710KL (https://octopart-clicks.com/click/altium?sku=311-10.0KCRCT-ND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) | 0805 (2012 Metric) | Digi-Key | 311-10.0KCRCT-ND (https://octopart-clicks.com/click/altium?sku=311-10.0KCRCT-ND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)
23 | R5, R6, R7, R13, R23, R24, R25 | 7 | 22R | RES SMD 22 OHM 1% 1/8W 0805 | Yageo (https://octopart-clicks.com/click/altium?sku=311-22.0CRCT-ND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) | RC0805FR-0722RL (https://octopart-clicks.com/click/altium?sku=311-22.0CRCT-ND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) | 0805 (2012 Metric) | Digi-Key | 311-22.0CRCT-ND (https://octopart-clicks.com/click/altium?sku=311-22.0CRCT-ND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)
24 | R8, R27 | 2 | 0R | RES 0.0 OHM 1/8W 0805 SMD | Yageo (https://octopart-clicks.com/click/altium?sku=311-0.0ARCT-ND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) | RC0805JR-070RL (https://octopart-clicks.com/click/altium?sku=311-0.0ARCT-ND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) | 0805 (2012 Metric) | Digi-Key | 311-0.0ARCT-ND (https://octopart-clicks.com/click/altium?sku=311-0.0ARCT-ND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)
25 | R9, R16 | 2 | 1M | RES SMD 1M OHM 1% 1/8W 0805 | Yageo (https://octopart-clicks.com/click/altium?sku=311-1.00MCRTR-ND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) | RC0805FR-071ML (https://octopart-clicks.com/click/altium?sku=311-1.00MCRTR-ND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) |  | Digi-Key | 311-1.00MCRTR-ND (https://octopart-clicks.com/click/altium?sku=311-1.00MCRTR-ND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)
26 | R10, R11, R12 | 3 | 1k | RES SMD 1K OHM 1% 1/8W 0805 | Yageo (https://octopart-clicks.com/click/altium?sku=311-1.00KCRCT-ND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) | RC0805FR-071KL (https://octopart-clicks.com/click/altium?sku=311-1.00KCRCT-ND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) | 0805 (2012 Metric) | Digi-Key | 311-1.00KCRCT-ND (https://octopart-clicks.com/click/altium?sku=311-1.00KCRCT-ND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)
27 | RV1, RV2 | 2 | CG0603MLC-05E | VARISTOR 0603 | Bourns (https://octopart-clicks.com/click/altium?sku=CG0603MLC-05ECT-ND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) | CG0603MLC-05E (https://octopart-clicks.com/click/altium?sku=CG0603MLC-05ECT-ND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) | 0603 (1608 Metric) | Digi-Key | CG0603MLC-05ECT-ND (https://octopart-clicks.com/click/altium?sku=CG0603MLC-05ECT-ND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)
28 | S1, S2 | 2 | 1825910-6 | SWITCH TACTILE SPST-NO 0.05A 24V | TE Connectivity Alcoswitch (https://octopart-clicks.com/click/altium?manufacturer=TE%20Connectivity%20Alcoswitch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) | 1825910-6 (https://octopart-clicks.com/click/altium?manufacturer=TE%20Connectivity%20Alcoswitch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) |  | Digi-Key | 450-1650-ND (https://octopart-clicks.com/click/altium?manufacturer=TE%20Connectivity%20Alcoswitch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)
29 | SCKT FOR U1 | 1 | 28-DIP Socket | CONN IC DIP SOCKET 28POS TIN | 3M (https://octopart-clicks.com/click/altium?sku=3M5480-ND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) | 4828-3004-CP (https://octopart-clicks.com/click/altium?sku=3M5480-ND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) |  | Digi-Key | 3M5480-ND (https://octopart-clicks.com/click/altium?sku=3M5480-ND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)
30 | U1 | 1 | ATMEGA328P-PU | ATMEL ATMEGA328P-PU 8 Bit Microcontroller, Low Power High Performance, ATmega, 20 MHz, 32 KB, 2 KB, 28 Pins, DIP | Microchip (https://octopart-clicks.com/click/altium?sku=ATMEGA328P-PU-ND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) | ATMEGA328P-PU (https://octopart-clicks.com/click/altium?sku=ATMEGA328P-PU-ND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) |  | Digi-Key | ATMEGA328P-PU-ND (https://octopart-clicks.com/click/altium?sku=ATMEGA328P-PU-ND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)
31 | U2 | 1 | ATMEGA16U2-AU | ATMEL ATMEGA16U2-AU MCU, 8BIT, MEGAAVR, 16MHZ, TQFP-32 | Microchip (https://octopart-clicks.com/click/altium?sku=ATMEGA16U2-AU-ND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) | ATMEGA16U2-AU (https://octopart-clicks.com/click/altium?sku=ATMEGA16U2-AU-ND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) |  | Digi-Key | ATMEGA16U2-AU-ND (https://octopart-clicks.com/click/altium?sku=ATMEGA16U2-AU-ND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)
32 | U3 | 1 | TL1963A-33DCQR | IC REG LDO 3.3V 1.5A SOT223-6 | Texas Instruments (https://octopart-clicks.com/click/altium?sku=296-24534-1-ND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) | TL1963A-33DCQR (https://octopart-clicks.com/click/altium?sku=296-24534-1-ND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) | SOT-223-6 | Digi-Key | 296-24534-1-ND (https://octopart-clicks.com/click/altium?sku=296-24534-1-ND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)
33 | U4 | 1 | NC7SZ00M5X | IC GATE NAND 1CH 2-INP SOT-23-5 | ON Semiconductor / Fairchild (https://octopart-clicks.com/click/altium?manufacturer=ON%20Semiconductor%20%2F%20Fairchild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) | NC7SZ00M5X (https://octopart-clicks.com/click/altium?manufacturer=ON%20Semiconductor%20%2F%20Fairchild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) |  | Digi-Key | NC7SZ00M5XCT-ND (https://octopart-clicks.com/click/altium?manufacturer=ON%20Semiconductor%20%2F%20Fairchild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)
34 | U5, U6, U7 | 3 | SN74AHC1G09DBVR | IC GATE AND SGL 2INP SOT23-5 | Texas Instruments (https://octopart-clicks.com/click/altium?sku=296-29202-1-ND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) | SN74AHC1G09DBVR (https://octopart-clicks.com/click/altium?sku=296-29202-1-ND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) | SC-74A, SOT-753 | Digi-Key | 296-29202-1-ND (https://octopart-clicks.com/click/altium?sku=296-29202-1-ND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)
35 | Y1, Y2 | 2 | ABM7-22.1184MHZ-D2Y-T | Crystals 22.1184MHz 20ppm 18pF -40C+85C | Abracon (https://octopart-clicks.com/click/altium?sku=535-9844-6-ND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) | ABM7-22.1184MHZ-D2Y-T (https://octopart-clicks.com/click/altium?sku=535-9844-6-ND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) |  | Digi-Key | 535-9844-6-ND (https://octopart-clicks.com/click/altium?sku=535-9844-6-ND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)
Approved |  |  |  |  | Notes

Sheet: Project Information
Project Full Path | C:\Users\Miguel Osuna\OneDrive\Documentos\Proyectos\PCB's Udemy\28 Pins\Design Files\V1I2\Mikeduino.PrjPcb
Project Filename | Mikeduino.PrjPcb
Variant Name | FIXED 5V
Data-Source Filename | Mikeduino.PrjPcb
Data-Source Full Path | C:\Users\Miguel Osuna\OneDrive\Documentos\Proyectos\PCB's Udemy\28 Pins\Design Files\V1I2\Mikeduino.PrjPcb
Title | Mikeduino.PrjPcb
Total Quantity | 95
Report Time | 1:34:42 AM
Report Date | 10/20/2018
Report Date & Tine | 10/20/2018 1:34:42 AM
Output Name | Mikeduino Component Reference Grouped
Output Type | BOM_PartType
Output Generator Name | BOM
Output Generator Description | Bill of Materials

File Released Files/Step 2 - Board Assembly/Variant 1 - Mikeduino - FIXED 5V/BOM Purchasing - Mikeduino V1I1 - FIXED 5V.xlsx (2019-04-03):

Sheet: Part List Report
 | Component list |  |  | Mikeduino
 | Source Data From: | Mikeduino.PrjPcb |  |  | Contact: |  |  |  | Generated by:
 | Project: | Mikeduino.PrjPcb
 | Variant: | FIXED 5V |  |  |  |  |  |  | FEDEVEL
 | Report Date: | 10/18/2018 | 12:35:13 PM |  |  |  |  |  | http://www.fedevel.com
 | Print Date: | 2018-10-26 | 21:58:48
# | Category | Manufacturer 1 | Manufacturer Part Number 1 | Package / Case | Description | Quantity | Supplier 1 | Supplier Part Number 1 | Supplier Order Qty 1 | Supplier Stock 1 | Supplier Unit Price 1 | Supplier Subtotal 1 | Supplier Currency 1 | Length(mm) | Width(mm) | #Column Name Error:Height(mm) | a
1 |  | Panasonic (https://octopart-clicks.com/click/altium?sku=P15782CT-ND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) | EEA-GA1A101B (https://octopart-clicks.com/click/altium?sku=P15782CT-ND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) |  | CAP ALUM 100UF 20% 10V RADIAL | 2 | Digi-Key | P15782CT-ND (https://octopart-clicks.com/click/altium?sku=P15782CT-ND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) | 2 | 5539 | 0.35 | 0.70 | USD
2 |  | Samsung (https://octopart-clicks.com/click/altium?sku=1276-2402-6-ND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) | CL21A106KPCLQNC (https://octopart-clicks.com/click/altium?sku=1276-2402-6-ND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) |  | Cap Ceramic 10uF 10V X5R 10% SMD 0805 85C Cardboard T/R | 7 | Digi-Key | 1276-2402-6-ND (https://octopart-clicks.com/click/altium?sku=1276-2402-6-ND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) | 7 | 40000 | 0.21 | 1.47 | USD
3 | Capacitors | TDK (https://octopart-clicks.com/click/altium?sku=445-7856-2-ND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) | CEU4J2X7R1H104K125AE (https://octopart-clicks.com/click/altium?sku=445-7856-2-ND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) |  | TDK CEU4J2X7R1H104K125AE SMD Multilayer Ceramic Capacitor, 0805 [2012 Metric], 0.1 F, 50 V, 10%, X7R, CEU Series | 19 | Digi-Key | 445-7856-2-ND (https://octopart-clicks.com/click/altium?sku=445-7856-2-ND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) |  | 12000 |  |  | USD | 2 | 1.2
4 | Capacitors | TDK (https://octopart-clicks.com/click/altium?sku=445-1419-1-ND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) | C2012X5R1E105K125AA (https://octopart-clicks.com/click/altium?sku=445-1419-1-ND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) | 0805 (2012 Metric) | CAP CER 1UF 25V 10% X5R 0805 | 1 | Digi-Key | 445-1419-1-ND (https://octopart-clicks.com/click/altium?sku=445-1419-1-ND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) | 1 | 0 | 0.21 | 0.21 | USD
5 |  | KEMET (https://octopart-clicks.com/click/altium?sku=399-1112-6-ND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) | C0805C180J5GAC-TU (https://octopart-clicks.com/click/altium?sku=399-1112-6-ND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) |  | KEMET 18pF Multilayer Ceramic Capacitor (MLCC) 50 V dc 5% C0G dielectric C SMD max op. temp. +125C | 4 | Digi-Key | 399-1112-6-ND (https://octopart-clicks.com/click/altium?sku=399-1112-6-ND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) | 4 | 0 | 0.16 | 0.64 | USD
6 | Optoelectronics | Osram Opto (https://octopart-clicks.com/click/altium?sku=475-2709-1-ND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) | Q65110A1746 (https://octopart-clicks.com/click/altium?sku=475-2709-1-ND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) | 0603 (1608 Metric) | LED SMARTLED GREEN 570NM 0603 | 1 | Digi-Key | 475-2709-1-ND (https://octopart-clicks.com/click/altium?sku=475-2709-1-ND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) | 1 | 532036 | 0.56 | 0.56 | USD
7 | Optoelectronics | Osram Opto (https://octopart-clicks.com/click/altium?sku=475-2740-1-ND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) | LOL29K-H2K1-24-Z (https://octopart-clicks.com/click/altium?sku=475-2740-1-ND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) | 0603 (1608 Metric) | LED SMARTLED ORANGE 606NM 0603 | 3 | Digi-Key | 475-2740-1-ND (https://octopart-clicks.com/click/altium?sku=475-2740-1-ND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) | 3 | 9314 | 0.49 | 1.47 | USD
8 | Discrete Semiconductor Products | ON Semiconductor / Fairchild (https://octopart-clicks.com/click/altium?manufacturer=ON%20Semiconductor%20%2F%20Fairchild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) | BAT54HT1G (https://octopart-clicks.com/click/altium?manufacturer=ON%20Semiconductor%20%2F%20Fairchild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) | SC-76, SOD-323 | DIODE SCHOTTKY 30V 0.2A SOD323 | 2 | Digi-Key | BAT54HT1GCT-ND (https://octopart-clicks.com/click/altium?manufacturer=ON%20Semiconductor%20%2F%20Fairchild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) |  | 0
9 |  | TDK (https://octopart-clicks.com/click/altium?sku=445-2206-6-ND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) | MPZ2012S601AT000 (https://octopart-clicks.com/click/altium?sku=445-2206-6-ND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) |  | TDK MPZ2012S601AT000 FERRITE BEAD, 0.1OHM, 2A, 0805, FULL REEL | 3 | Digi-Key | 445-2206-6-ND (https://octopart-clicks.com/click/altium?sku=445-2206-6-ND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) | 3 | 130950 | 0.11 | 0.33 | USD
10 |  | Harwin (https://octopart-clicks.com/click/altium?sku=952-1823-ND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) | M20-7820842 (https://octopart-clicks.com/click/altium?sku=952-1823-ND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) |  | Headers & Wire Housings 8 PIN SIL VERTICAL SOCKET GOLD+TIN | 2 | Digi-Key | 952-1823-ND (https://octopart-clicks.com/click/altium?sku=952-1823-ND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) | 2 | 1362 | 1.10 | 2.20 | USD
11 |  | Harwin (https://octopart-clicks.com/click/altium?sku=952-1809-ND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) | M20-7820646 (https://octopart-clicks.com/click/altium?sku=952-1809-ND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) |  | Headers & Wire Housings 6 PIN SIL VERTICAL SOCKET TIN | 1 | Digi-Key | 952-1809-ND (https://octopart-clicks.com/click/altium?sku=952-1809-ND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) | 1 | 2908 | 0.96 | 0.96 | USD
12 |  | Harwin (https://octopart-clicks.com/click/altium?sku=952-1847-ND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) | M20-7821046 (https://octopart-clicks.com/click/altium?sku=952-1847-ND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) |  | Headers & Wire Housings 10 PIN SIL VERTICAL SOCKET TIN | 1 | Digi-Key | 952-1847-ND (https://octopart-clicks.com/click/altium?sku=952-1847-ND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) | 1 | 249 | 1.28 | 1.28 | USD
13 |  | Amphenol FCI (https://octopart-clicks.com/click/altium?sku=609-3234-ND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) | 67997-206HLF (https://octopart-clicks.com/click/altium?sku=609-3234-ND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) |  | 6 Positions Header, Unshrouded Connector 0.100" (2.54mm) Through Hole Gold or Gold, GXT™ | 2 | Digi-Key | 609-3234-ND (https://octopart-clicks.com/click/altium?sku=609-3234-ND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) | 2 | 12321 | 0.32 | 0.64 | USD
14 | Connectors, Interconnects | Amphenol FCI (https://octopart-clicks.com/click/altium?sku=609-4616-1-ND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) | 10118193-0001LF (https://octopart-clicks.com/click/altium?sku=609-4616-1-ND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) |  | CONN USB MICRO B RECPT SMT R/A | 1 | Digi-Key | 609-4616-1-ND (https://octopart-clicks.com/click/altium?sku=609-4616-1-ND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) | 1 | 138970 | 0.42 | 0.42 | USD
15 | Connectors, Interconnects | Amphenol FCI (https://octopart-clicks.com/click/altium?sku=609-3234-ND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) | 67997-206HLF (https://octopart-clicks.com/click/altium?sku=609-3234-ND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) |  | 6 Positions Header, Unshrouded Connector 0.100" (2.54mm) Through Hole Gold or Gold, GXT™ | 1 | Digi-Key | 609-3234-ND (https://octopart-clicks.com/click/altium?sku=609-3234-ND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) | 1 | 12321 | 0.32 | 0.32 | USD | 7.62 | 5.05
16 | Connectors, Interconnects | Amphenol FCI (https://octopart-clicks.com/click/altium?sku=609-3461-ND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) | 68000-103HLF (https://octopart-clicks.com/click/altium?sku=609-3461-ND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) |  | BERGSTIK II .100" SR STRAIGHT | 1 | Digi-Key | 609-3461-ND (https://octopart-clicks.com/click/altium?sku=609-3461-ND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) | 1 | 55550 | 0.29 | 0.29 | USD
17 | Connectors, Interconnects | Amphenol FCI (https://octopart-clicks.com/click/altium?sku=609-3402-ND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) | 68001-204HLF (https://octopart-clicks.com/click/altium?sku=609-3402-ND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) |  | CONN HEADER 4POS .100 STR 15AU | 1 | Digi-Key | 609-3402-ND (https://octopart-clicks.com/click/altium?sku=609-3402-ND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) | 1 | 51 | 0.37 | 0.37 | USD
18 | Inductors, Coils, Chokes | KEMET (https://octopart-clicks.com/click/altium?sku=399-9598-1-ND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) | L1210R2R2MDWIT (https://octopart-clicks.com/click/altium?sku=399-9598-1-ND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) | 1210 (3225 Metric) | FIXED IND 2.2UH 2A 80 MOHM SMD | 1 | Digi-Key | 399-9598-1-ND (https://octopart-clicks.com/click/altium?sku=399-9598-1-ND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) | 1 | 12626 | 0.55 | 0.55 | USD
19 | Connectors, Interconnects | Sullins (https://octopart-clicks.com/click/altium?sku=S9337-ND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) | QPC02SXGN-RC (https://octopart-clicks.com/click/altium?sku=S9337-ND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) |  | CONN JUMPER SHORTING .100" GOLD | 2 | Digi-Key | S9337-ND (https://octopart-clicks.com/click/altium?sku=S9337-ND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) | 2 | 739009 | 0.10 | 0.20 | USD
20 | Resistors | Yageo (https://octopart-clicks.com/click/altium?sku=311-100KCRCT-ND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) | RC0805FR-07100KL (https://octopart-clicks.com/click/altium?sku=311-100KCRCT-ND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) | 0805 (2012 Metric) | RES SMD 100K OHM 1% 1/8W 0805 | 1 | Digi-Key | 311-100KCRCT-ND (https://octopart-clicks.com/click/altium?sku=311-100KCRCT-ND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) | 1 | 12323998 | 0.10 | 0.10 | USD | 2 | 1.2
21 | Resistors | Yageo Phycomp (https://octopart-clicks.com/click/altium?sku=311-560CRCT-ND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) | RC0805FR-07560RL (https://octopart-clicks.com/click/altium?sku=311-560CRCT-ND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) | 0805 (2012 Metric) | RES SMD 560 OHM 1% 1/8W 0805 | 5 | Digi-Key | 311-560CRCT-ND (https://octopart-clicks.com/click/altium?sku=311-560CRCT-ND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) | 5 | 0 | 0.10 | 0.50 | USD | 2 | 1.2
22 | Resistors | Yageo (https://octopart-clicks.com/click/altium?sku=311-10.0KCRCT-ND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) | RC0805FR-0710KL (https://octopart-clicks.com/click/altium?sku=311-10.0KCRCT-ND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) | 0805 (2012 Metric) | RES SMD 10K OHM 1% 1/8W 0805 | 6 | Digi-Key | 311-10.0KCRCT-ND (https://octopart-clicks.com/click/altium?sku=311-10.0KCRCT-ND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) | 6 | 31019181 | 0.10 | 0.60 | USD | 2 | 1.2
23 | Resistors | Yageo (https://octopart-clicks.com/click/altium?sku=311-22.0CRCT-ND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) | RC0805FR-0722RL (https://octopart-clicks.com/click/altium?sku=311-22.0CRCT-ND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) | 0805 (2012 Metric) | RES SMD 22 OHM 1% 1/8W 0805 | 7 | Digi-Key | 311-22.0CRCT-ND (https://octopart-clicks.com/click/altium?sku=311-22.0CRCT-ND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) | 7 | 418683 | 0.10 | 0.70 | USD | 2 | 1.2
24 | Resistors | Yageo (https://octopart-clicks.com/click/altium?sku=311-0.0ARCT-ND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) | RC0805JR-070RL (https://octopart-clicks.com/click/altium?sku=311-0.0ARCT-ND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) | 0805 (2012 Metric) | RES 0.0 OHM 1/8W 0805 SMD | 2 | Digi-Key | 311-0.0ARCT-ND (https://octopart-clicks.com/click/altium?sku=311-0.0ARCT-ND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) | 2 | 0 | 0.10 | 0.20 | USD
25 | Resistors | Yageo Phycomp (https://octopart-clicks.com/click/altium?sku=311-1.00MCRTR-ND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) | RC0805FR-071ML (https://octopart-clicks.com/click/altium?sku=311-1.00MCRTR-ND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) |  | RES SMD 1M OHM 1% 1/8W 0805 | 2 | Digi-Key | 311-1.00MCRTR-ND (https://octopart-clicks.com/click/altium?sku=311-1.00MCRTR-ND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) |  | 7165000 |  |  | USD | 2 | 1.2
26 | Resistors | Yageo (https://octopart-clicks.com/click/altium?sku=311-1.00KCRCT-ND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) | RC0805FR-071KL (https://octopart-clicks.com/click/altium?sku=311-1.00KCRCT-ND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) | 0805 (2012 Metric) | RES SMD 1K OHM 1% 1/8W 0805 | 3 | Digi-Key | 311-1.00KCRCT-ND (https://octopart-clicks.com/click/altium?sku=311-1.00KCRCT-ND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) | 3 | 20449006 | 0.10 | 0.30 | USD | 2 | 1.2
27 | Circuit Protection | Bourns (https://octopart-clicks.com/click/altium?sku=CG0603MLC-05ECT-ND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) | CG0603MLC-05E (https://octopart-clicks.com/click/altium?sku=CG0603MLC-05ECT-ND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) | 0603 (1608 Metric) | VARISTOR 0603 | 2 | Digi-Key | CG0603MLC-05ECT-ND (https://octopart-clicks.com/click/altium?sku=CG0603MLC-05ECT-ND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) | 2 | 306997 | 0.51 | 1.02 | USD | 1.7 | 0.8
28 | Switches | TE Connectivity Alcoswitch (https://octopart-clicks.com/click/altium?manufacturer=TE%20Connectivity%20Alcoswitch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) | 1825910-6 (https://octopart-clicks.com/click/altium?manufacturer=TE%20Connectivity%20Alcoswitch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) |  | SWITCH TACTILE SPST-NO 0.05A 24V | 2 | Digi-Key | 450-1650-ND (https://octopart-clicks.com/click/altium?manufacturer=TE%20Connectivity%20Alcoswitch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) | 2 | 73346 | 0.10 | 0.20 | USD | 7.8 | 6
29 | Connectors, Interconnects | 3M (https://octopart-clicks.com/click/altium?sku=3M5480-ND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) | 4828-3004-CP (https://octopart-clicks.com/click/altium?sku=3M5480-ND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) |  | CONN IC DIP SOCKET 28POS TIN | 1 | Digi-Key | 3M5480-ND (https://octopart-clicks.com/click/altium?sku=3M5480-ND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) | 1 | 12317 | 0.77 | 0.77 | USD
30 |  | Microchip / Atmel (https://octopart-clicks.com/click/altium?manufacturer=Microchip%20%2F%20Atmel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) | ATMEGA328P-PU (https://octopart-clicks.com/click/altium?manufacturer=Microchip%20%2F%20Atmel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) |  | ATMEL ATMEGA328P-PU 8 Bit Microcontroller, Low Power High Performance, ATmega, 20 MHz, 32 KB, 2 KB, 28 Pins, DIP | 1 | Digi-Key | ATMEGA328P-PU-ND (https://octopart-clicks.com/click/altium?manufacturer=Microchip%20%2F%20Atmel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) | 1 | 17660 | 2.14 | 2.14 | USD
31 |  | Microchip (https://octopart-clicks.com/click/altium?sku=ATMEGA16U2-AU-ND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) | ATMEGA16U2-AU (https://octopart-clicks.com/click/altium?sku=ATMEGA16U2-AU-ND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) |  | ATMEL ATMEGA16U2-AU MCU, 8BIT, MEGAAVR, 16MHZ, TQFP-32 | 1 | Digi-Key | ATMEGA16U2-AU-ND (https://octopart-clicks.com/click/altium?sku=ATMEGA16U2-AU-ND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) | 1 | 3944 | 2.52 | 2.52 | USD
32 | Integrated Circuits (ICs) | Texas Instruments (https://octopart-clicks.com/click/altium?sku=296-24534-1-ND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) | TL1963A-33DCQR (https://octopart-clicks.com/click/altium?sku=296-24534-1-ND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) | SOT-223-6 | IC REG LDO 3.3V 1.5A SOT223-6 | 1 | Digi-Key | 296-24534-1-ND (https://octopart-clicks.com/click/altium?sku=296-24534-1-ND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) | 1 | 1807 | 2.88 | 2.88 | USD
33 |  | ON Semiconductor / Fairchild (https://octopart-clicks.com/click/altium?manufacturer=ON%20Semiconductor%20%2F%20Fairchild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) | NC7SZ00M5X (https://octopart-clicks.com/click/altium?manufacturer=ON%20Semiconductor%20%2F%20Fairchild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) |  | IC GATE NAND 1CH 2-INP SOT-23-5 | 1 | Digi-Key | NC7SZ00M5XCT-ND (https://octopart-clicks.com/click/altium?manufacturer=ON%20Semiconductor%20%2F%20Fairchild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) | 1 | 64570 | 0.39 | 0.39 | USD
34 | Integrated Circuits (ICs) | Texas Instruments (https://octopart-clicks.com/click/altium?sku=296-29202-1-ND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) | SN74AHC1G09DBVR (https://octopart-clicks.com/click/altium?sku=296-29202-1-ND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) | SC-74A, SOT-753 | IC GATE AND SGL 2INP SOT23-5 | 3 | Digi-Key | 296-29202-1-ND (https://octopart-clicks.com/click/altium?sku=296-29202-1-ND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) | 3 | 76365 | 0.43 | 1.29 | USD
35 |  | Abracon (https://octopart-clicks.com/click/altium?sku=535-9844-6-ND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) | ABM7-22.1184MHZ-D2Y-T (https://octopart-clicks.com/click/altium?sku=535-9844-6-ND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) |  | Crystals 22.1184MHz 20ppm 18pF -40C+85C | 2 | Digi-Key | 535-9844-6-ND (https://octopart-clicks.com/click/altium?sku=535-9844-6-ND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) | 2 | 5189 | 1.00 | 2.00 | USD
 |  |  |  |  |  | 95 |  |  | 72 |  |  | 28.22 |  | 0 | 0 | 0
Approved |  |  |  | Notes
 |  |  |  |  |  | 1 | pcs: | Total |  | 28.22 |  | <none>
 |  |  |  |  |  |  |  | Price for 1pcs |  | 28.22 |  | <none>

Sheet: Project Information
Project Full Path | C:\Users\Miguel Osuna\OneDrive\Documentos\Proyectos\PCB's Udemy\28 Pins\Design Files\V1I2\Mikeduino.PrjPcb
Project Filename | Mikeduino.PrjPcb
Variant Name | FIXED 5V
Data-Source Filename | Mikeduino.PrjPcb
Data-Source Full Path | C:\Users\Miguel Osuna\OneDrive\Documentos\Proyectos\PCB's Udemy\28 Pins\Design Files\V1I2\Mikeduino.PrjPcb
Title | Mikeduino
Total Quantity | 95
Report Time | 12:35:13 PM
Report Date | 10/18/2018
Report Date & Tine | 10/18/2018 12:35:13 PM
Output Name | Mikeduino BOM
Output Type | BOM_PartType
Output Generator Name | BOM
Output Generator Description | Bill of Materials

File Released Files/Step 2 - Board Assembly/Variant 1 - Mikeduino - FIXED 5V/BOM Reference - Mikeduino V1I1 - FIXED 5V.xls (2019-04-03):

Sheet: Part List Report
 | Component reference list |  |  | Mikeduino
 |  | Source Data From: | Mikeduino.PrjPcb |  | Contact: |  | Generated by:
 |  | Project: | Mikeduino.PrjPcb
 |  | Variant: | FIXED 5V |  |  |  | FEDEVEL
 | Report Date: | 10/18/2018 | 12:33:01 PM |  |  |  | http://www.fedevel.com
 | Print Date: | 2018-10-18 | 12:33:19
# | Designator | Comment | Description | Manufacturer 1 | Manufacturer Part Number 1 | Package / Case | Supplier 1 | Supplier Part Number 1
1 | C1 | 100uF / 10V | CAP ALUM 100UF 20% 10V RADIAL | Panasonic (https://octopart-clicks.com/click/altium?sku=P15782CT-ND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) | EEA-GA1A101B (https://octopart-clicks.com/click/altium?sku=P15782CT-ND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) |  | Digi-Key | P15782CT-ND (https://octopart-clicks.com/click/altium?sku=P15782CT-ND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)
2 | C2 | 100uF / 10V | CAP ALUM 100UF 20% 10V RADIAL | Panasonic (https://octopart-clicks.com/click/altium?sku=P15782CT-ND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) | EEA-GA1A101B (https://octopart-clicks.com/click/altium?sku=P15782CT-ND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) |  | Digi-Key | P15782CT-ND (https://octopart-clicks.com/click/altium?sku=P15782CT-ND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)
3 | C3 | 10uF / 10V | Cap Ceramic 10uF 10V X5R 10% SMD 0805 85C Cardboard T/R | Samsung (https://octopart-clicks.com/click/altium?sku=1276-2402-6-ND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) | CL21A106KPCLQNC (https://octopart-clicks.com/click/altium?sku=1276-2402-6-ND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) |  | Digi-Key | 1276-2402-6-ND (https://octopart-clicks.com/click/altium?sku=1276-2402-6-ND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)
4 | C4 | 100nF | TDK CEU4J2X7R1H104K125AE SMD Multilayer Ceramic Capacitor, 0805 [2012 Metric], 0.1 F, 50 V, 10%, X7R, CEU Series | TDK (https://octopart-clicks.com/click/altium?sku=445-7856-2-ND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) | CEU4J2X7R1H104K125AE (https://octopart-clicks.com/click/altium?sku=445-7856-2-ND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) |  | Digi-Key | 445-7856-2-ND (https://octopart-clicks.com/click/altium?sku=445-7856-2-ND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)
5 | C5 | 100nF | TDK CEU4J2X7R1H104K125AE SMD Multilayer Ceramic Capacitor, 0805 [2012 Metric], 0.1 F, 50 V, 10%, X7R, CEU Series | TDK (https://octopart-clicks.com/click/altium?sku=445-7856-2-ND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) | CEU4J2X7R1H104K125AE (https://octopart-clicks.com/click/altium?sku=445-7856-2-ND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) |  | Digi-Key | 445-7856-2-ND (https://octopart-clicks.com/click/altium?sku=445-7856-2-ND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)
6 | C6 | 100nF | TDK CEU4J2X7R1H104K125AE SMD Multilayer Ceramic Capacitor, 0805 [2012 Metric], 0.1 F, 50 V, 10%, X7R, CEU Series | TDK (https://octopart-clicks.com/click/altium?sku=445-7856-2-ND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) | CEU4J2X7R1H104K125AE (https://octopart-clicks.com/click/altium?sku=445-7856-2-ND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) |  | Digi-Key | 445-7856-2-ND (https://octopart-clicks.com/click/altium?sku=445-7856-2-ND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)
7 | C7 | 1uF / 25V | CAP CER 1UF 25V 10% X5R 0805 | TDK (https://octopart-clicks.com/click/altium?sku=445-1419-1-ND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) | C2012X5R1E105K125AA (https://octopart-clicks.com/click/altium?sku=445-1419-1-ND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) | 0805 (2012 Metric) | Digi-Key | 445-1419-1-ND (https://octopart-clicks.com/click/altium?sku=445-1419-1-ND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)
8 | C8 | 100nF | TDK CEU4J2X7R1H104K125AE SMD Multilayer Ceramic Capacitor, 0805 [2012 Metric], 0.1 F, 50 V, 10%, X7R, CEU Series | TDK (https://octopart-clicks.com/click/altium?sku=445-7856-2-ND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) | CEU4J2X7R1H104K125AE (https://octopart-clicks.com/click/altium?sku=445-7856-2-ND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) |  | Digi-Key | 445-7856-2-ND (https://octopart-clicks.com/click/altium?sku=445-7856-2-ND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)
9 | C9 | 18p | KEMET 18pF Multilayer Ceramic Capacitor (MLCC) 50 V dc 5% C0G dielectric C SMD max op. temp. +125C | KEMET (https://octopart-clicks.com/click/altium?sku=399-1112-6-ND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) | C0805C180J5GAC-TU (https://octopart-clicks.com/click/altium?sku=399-1112-6-ND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) |  | Digi-Key | 399-1112-6-ND (https://octopart-clicks.com/click/altium?sku=399-1112-6-ND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)
10 | C10 | 18p | KEMET 18pF Multilayer Ceramic Capacitor (MLCC) 50 V dc 5% C0G dielectric C SMD max op. temp. +125C | KEMET (https://octopart-clicks.com/click/altium?sku=399-1112-6-ND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) | C0805C180J5GAC-TU (https://octopart-clicks.com/click/altium?sku=399-1112-6-ND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) |  | Digi-Key | 399-1112-6-ND (https://octopart-clicks.com/click/altium?sku=399-1112-6-ND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)
11 | C11 | 100nF | TDK CEU4J2X7R1H104K125AE SMD Multilayer Ceramic Capacitor, 0805 [2012 Metric], 0.1 F, 50 V, 10%, X7R, CEU Series | TDK (https://octopart-clicks.com/click/altium?sku=445-7856-2-ND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) | CEU4J2X7R1H104K125AE (https://octopart-clicks.com/click/altium?sku=445-7856-2-ND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) |  | Digi-Key | 445-7856-2-ND (https://octopart-clicks.com/click/altium?sku=445-7856-2-ND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)
12 | C12 | 10uF / 10V | Cap Ceramic 10uF 10V X5R 10% SMD 0805 85C Cardboard T/R | Samsung (https://octopart-clicks.com/click/altium?sku=1276-2402-6-ND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) | CL21A106KPCLQNC (https://octopart-clicks.com/click/altium?sku=1276-2402-6-ND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) |  | Digi-Key | 1276-2402-6-ND (https://octopart-clicks.com/click/altium?sku=1276-2402-6-ND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)
13 | C13 | 10uF / 10V | Cap Ceramic 10uF 10V X5R 10% SMD 0805 85C Cardboard T/R | Samsung (https://octopart-clicks.com/click/altium?sku=1276-2402-6-ND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) | CL21A106KPCLQNC (https://octopart-clicks.com/click/altium?sku=1276-2402-6-ND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) |  | Digi-Key | 1276-2402-6-ND (https://octopart-clicks.com/click/altium?sku=1276-2402-6-ND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)
14 | C14 | 100nF | TDK CEU4J2X7R1H104K125AE SMD Multilayer Ceramic Capacitor, 0805 [2012 Metric], 0.1 F, 50 V, 10%, X7R, CEU Series | TDK (https://octopart-clicks.com/click/altium?sku=445-7856-2-ND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) | CEU4J2X7R1H104K125AE (https://octopart-clicks.com/click/altium?sku=445-7856-2-ND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) |  | Digi-Key | 445-7856-2-ND (https://octopart-clicks.com/click/altium?sku=445-7856-2-ND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)
15 | C15 | 100nF | TDK CEU4J2X7R1H104K125AE SMD Multilayer Ceramic Capacitor, 0805 [2012 Metric], 0.1 F, 50 V, 10%, X7R, CEU Series | TDK (https://octopart-clicks.com/click/altium?sku=445-7856-2-ND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) | CEU4J2X7R1H104K125AE (https://octopart-clicks.com/click/altium?sku=445-7856-2-ND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) |  | Digi-Key | 445-7856-2-ND (https://octopart-clicks.com/click/altium?sku=445-7856-2-ND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)
16 | C16 | 100nF | TDK CEU4J2X7R1H104K125AE SMD Multilayer Ceramic Capacitor, 0805 [2012 Metric], 0.1 F, 50 V, 10%, X7R, CEU Series | TDK (https://octopart-clicks.com/click/altium?sku=445-7856-2-ND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) | CEU4J2X7R1H104K125AE (https://octopart-clicks.com/click/altium?sku=445-7856-2-ND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) |  | Digi-Key | 445-7856-2-ND (https://octopart-clicks.com/click/altium?sku=445-7856-2-ND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)
17 | C17 | 100nF | TDK CEU4J2X7R1H104K125AE SMD Multilayer Ceramic Capacitor, 0805 [2012 Metric], 0.1 F, 50 V, 10%, X7R, CEU Series | TDK (https://octopart-clicks.com/click/altium?sku=445-7856-2-ND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) | CEU4J2X7R1H104K125AE (https://octopart-clicks.com/click/altium?sku=445-7856-2-ND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) |  | Digi-Key | 445-7856-2-ND (https://octopart-clicks.com/click/altium?sku=445-7856-2-ND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)
18 | C19 | 10uF / 10V | Cap Ceramic 10uF 10V X5R 10% SMD 0805 85C Cardboard T/R | Samsung (https://octopart-clicks.com/click/altium?sku=1276-2402-6-ND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) | CL21A106KPCLQNC (https://octopart-clicks.com/click/altium?sku=1276-2402-6-ND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) |  | Digi-Key | 1276-2402-6-ND (https://octopart-clicks.com/click/altium?sku=1276-2402-6-ND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)
19 | C20 | 100nF | TDK CEU4J2X7R1H104K125AE SMD Multilayer Ceramic Capacitor, 0805 [2012 Metric], 0.1 F, 50 V, 10%, X7R, CEU Series | TDK (https://octopart-clicks.com/click/altium?sku=445-7856-2-ND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) | CEU4J2X7R1H104K125AE (https://octopart-clicks.com/click/altium?sku=445-7856-2-ND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) |  | Digi-Key | 445-7856-2-ND (https://octopart-clicks.com/click/altium?sku=445-7856-2-ND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)
20 | C21 | 10uF / 10V | Cap Ceramic 10uF 10V X5R 10% SMD 0805 85C Cardboard T/R | Samsung (https://octopart-clicks.com/click/altium?sku=1276-2402-6-ND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) | CL21A106KPCLQNC (https://octopart-clicks.com/click/altium?sku=1276-2402-6-ND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) |  | Digi-Key | 1276-2402-6-ND (https://octopart-clicks.com/click/altium?sku=1276-2402-6-ND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)
21 | C22 | 10uF / 10V | Cap Ceramic 10uF 10V X5R 10% SMD 0805 85C Cardboard T/R | Samsung (https://octopart-clicks.com/click/altium?sku=1276-2402-6-ND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) | CL21A106KPCLQNC (https://octopart-clicks.com/click/altium?sku=1276-2402-6-ND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) |  | Digi-Key | 1276-2402-6-ND (https://octopart-clicks.com/click/altium?sku=1276-2402-6-ND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)
22 | C23 | 100nF | TDK CEU4J2X7R1H104K125AE SMD Multilayer Ceramic Capacitor, 0805 [2012 Metric], 0.1 F, 50 V, 10%, X7R, CEU Series | TDK (https://octopart-clicks.com/click/altium?sku=445-7856-2-ND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) | CEU4J2X7R1H104K125AE (https://octopart-clicks.com/click/altium?sku=445-7856-2-ND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) |  | Digi-Key | 445-7856-2-ND (https://octopart-clicks.com/click/altium?sku=445-7856-2-ND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)
23 | C24 | 100nF | TDK CEU4J2X7R1H104K125AE SMD Multilayer Ceramic Capacitor, 0805 [2012 Metric], 0.1 F, 50 V, 10%, X7R, CEU Series | TDK (https://octopart-clicks.com/click/altium?sku=445-7856-2-ND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) | CEU4J2X7R1H104K125AE (https://octopart-clicks.com/click/altium?sku=445-7856-2-ND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) |  | Digi-Key | 445-7856-2-ND (https://octopart-clicks.com/click/altium?sku=445-7856-2-ND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)
24 | C25 | 18p | KEMET 18pF Multilayer Ceramic Capacitor (MLCC) 50 V dc 5% C0G dielectric C SMD max op. temp. +125C | KEMET (https://octopart-clicks.com/click/altium?sku=399-1112-6-ND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) | C0805C180J5GAC-TU (https://octopart-clicks.com/click/altium?sku=399-1112-6-ND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) |  | Digi-Key | 399-1112-6-ND (https://octopart-clicks.com/click/altium?sku=399-1112-6-ND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)
25 | C26 | 100nF | TDK CEU4J2X7R1H104K125AE SMD Multilayer Ceramic Capacitor, 0805 [2012 Metric], 0.1 F, 50 V, 10%, X7R, CEU Series | TDK (https://octopart-clicks.com/click/altium?sku=445-7856-2-ND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) | CEU4J2X7R1H104K125AE (https://octopart-clicks.com/click/altium?sku=445-7856-2-ND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) |  | Digi-Key | 445-7856-2-ND (https://octopart-clicks.com/click/altium?sku=445-7856-2-ND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)
26 | C27 | 18p | KEMET 18pF Multilayer Ceramic Capacitor (MLCC) 50 V dc 5% C0G dielectric C SMD max op. temp. +125C | KEMET (https://octopart-clicks.com/click/altium?sku=399-1112-6-ND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) | C0805C180J5GAC-TU (https://octopart-clicks.com/click/altium?sku=399-1112-6-ND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) |  | Digi-Key | 399-1112-6-ND (https://octopart-clicks.com/click/altium?sku=399-1112-6-ND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)
27 | C28 | 100nF | TDK CEU4J2X7R1H104K125AE SMD Multilayer Ceramic Capacitor, 0805 [2012 Metric], 0.1 F, 50 V, 10%, X7R, CEU Series | TDK (https://octopart-clicks.com/click/altium?sku=445-7856-2-ND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) | CEU4J2X7R1H104K125AE (https://octopart-clicks.com/click/altium?sku=445-7856-2-ND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) |  | Digi-Key | 445-7856-2-ND (https://octopart-clicks.com/click/altium?sku=445-7856-2-ND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)
28 | C29 | 100nF | TDK CEU4J2X7R1H104K125AE SMD Multilayer Ceramic Capacitor, 0805 [2012 Metric], 0.1 F, 50 V, 10%, X7R, CEU Series | TDK (https://octopart-clicks.com/click/altium?sku=445-7856-2-ND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) | CEU4J2X7R1H104K125AE (https://octopart-clicks.com/click/altium?sku=445-7856-2-ND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) |  | Digi-Key | 445-7856-2-ND (https://octopart-clicks.com/click/altium?sku=445-7856-2-ND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)
29 | C30 | 100nF | TDK CEU4J2X7R1H104K125AE SMD Multilayer Ceramic Capacitor, 0805 [2012 Metric], 0.1 F, 50 V, 10%, X7R, CEU Series | TDK (https://octopart-clicks.com/click/altium?sku=445-7856-2-ND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) | CEU4J2X7R1H104K125AE (https://octopart-clicks.com/click/altium?sku=445-7856-2-ND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) |  | Digi-Key | 445-7856-2-ND (https://octopart-clicks.com/click/altium?sku=445-7856-2-ND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)
30 | C31 | 100nF | TDK CEU4J2X7R1H104K125AE SMD Multilayer Ceramic Capacitor, 0805 [2012 Metric], 0.1 F, 50 V, 10%, X7R, CEU Series | TDK (https://octopart-clicks.com/click/altium?sku=445-7856-2-ND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) | CEU4J2X7R1H104K125AE (https://octopart-clicks.com/click/altium?sku=445-7856-2-ND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) |  | Digi-Key | 445-7856-2-ND (https://octopart-clicks.com/click/altium?sku=445-7856-2-ND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)
31 | C32 | 100nF | TDK CEU4J2X7R1H104K125AE SMD Multilayer Ceramic Capacitor, 0805 [2012 Metric], 0.1 F, 50 V, 10%, X7R, CEU Series | TDK (https://octopart-clicks.com/click/altium?sku=445-7856-2-ND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) | CEU4J2X7R1H104K125AE (https://octopart-clicks.com/click/altium?sku=445-7856-2-ND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) |  | Digi-Key | 445-7856-2-ND (https://octopart-clicks.com/click/altium?sku=445-7856-2-ND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)
32 | C33 | 100nF | TDK CEU4J2X7R1H104K125AE SMD Multilayer Ceramic Capacitor, 0805 [2012 Metric], 0.1 F, 50 V, 10%, X7R, CEU Series | TDK (https://octopart-clicks.com/click/altium?sku=445-7856-2-ND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) | CEU4J2X7R1H104K125AE (https://octopart-clicks.com/click/altium?sku=445-7856-2-ND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) |  | Digi-Key | 445-7856-2-ND (https://octopart-clicks.com/click/altium?sku=445-7856-2-ND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)
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

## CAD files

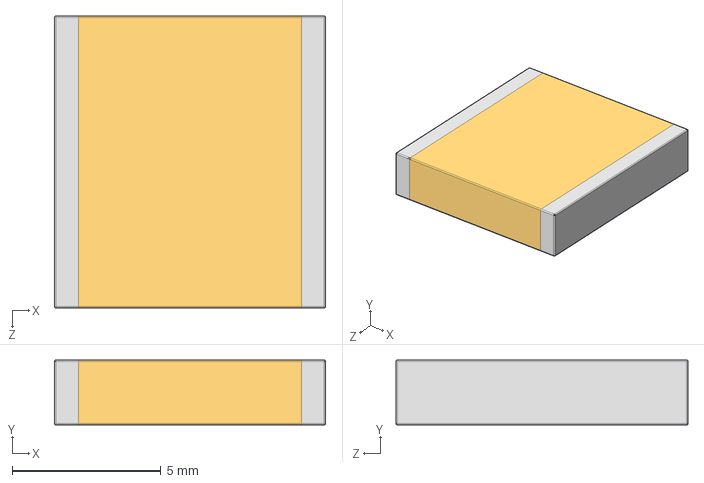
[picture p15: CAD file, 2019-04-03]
Design Documentation/3D Models/CAPC/CAPC9198X218N EIA 3640.step
9.10 x 2.18 x 9.80 mm

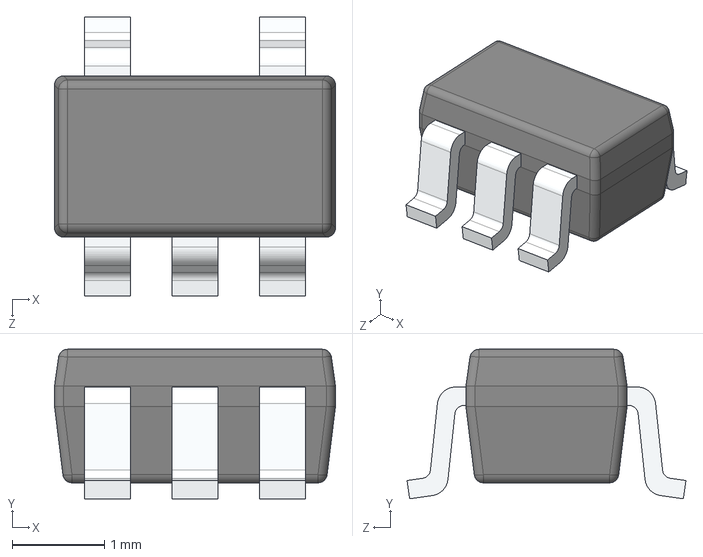
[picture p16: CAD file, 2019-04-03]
Design Documentation/3D Models/User Library-TPS79333DBVR.step
3.05 x 1.62 x 3.03 mm

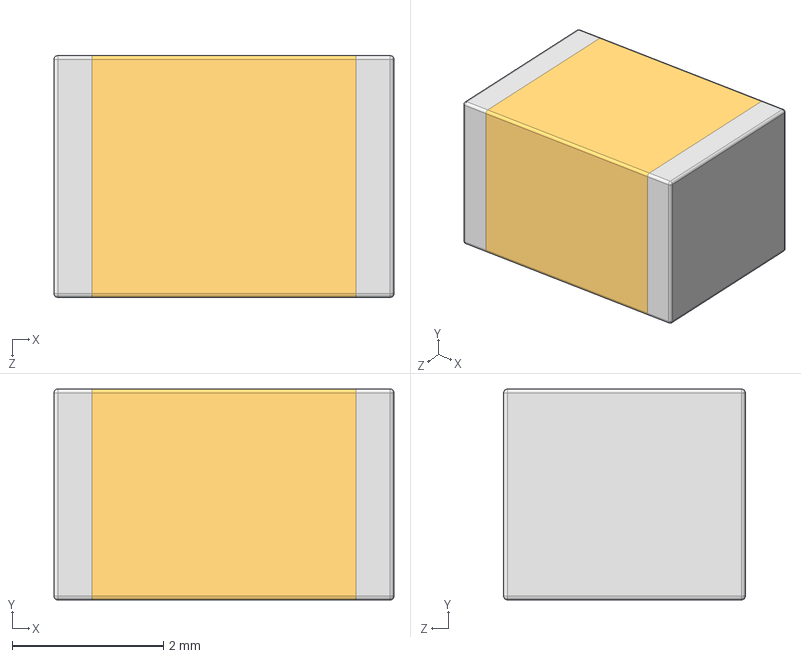
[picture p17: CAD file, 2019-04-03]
Design Documentation/3D Models/CAPC/CAPC4532X279N EIA 1812.step
4.50 x 2.79 x 3.20 mm

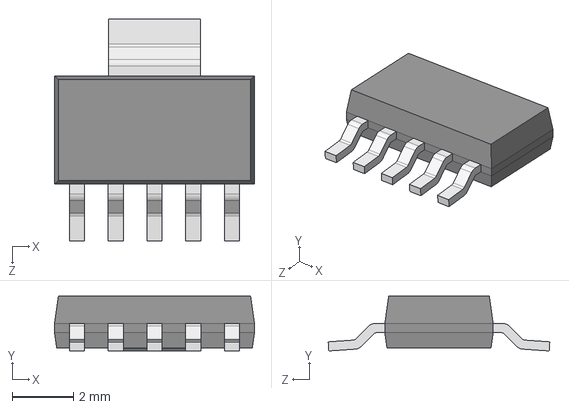
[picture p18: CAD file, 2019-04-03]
Design Documentation/3D Models/User Library-TPS73701DCQ.step
6.55 x 1.80 x 7.26 mm

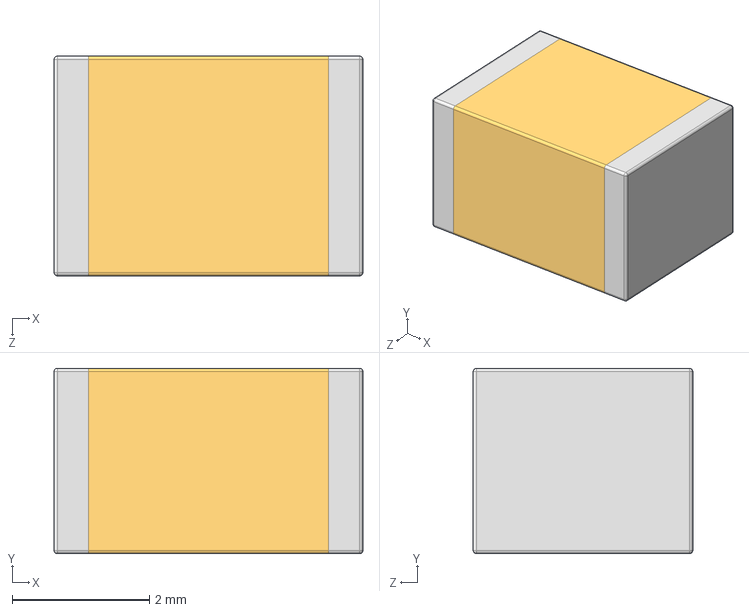
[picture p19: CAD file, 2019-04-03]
Design Documentation/3D Models/CAPC/CAPC4532X270N EIA 1812.step
4.50 x 2.70 x 3.20 mm

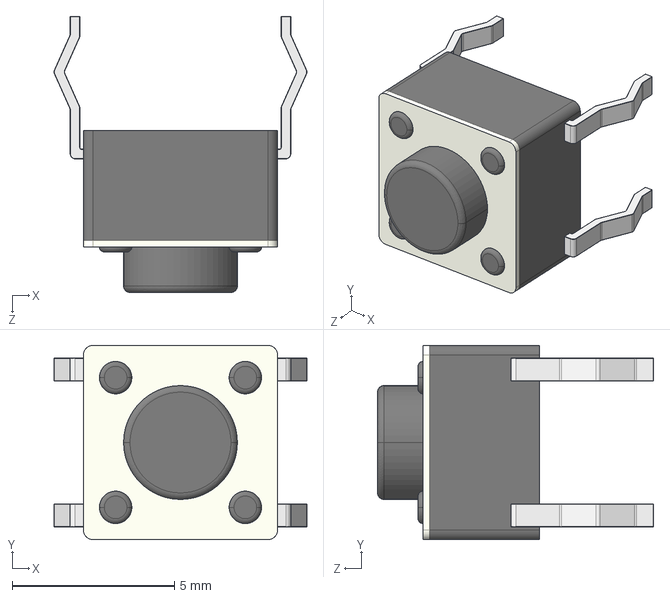
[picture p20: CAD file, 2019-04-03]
Design Documentation/3D Models/User Library-FSM4JLH(1825910-5).step
7.80 x 5.99 x 8.51 mm

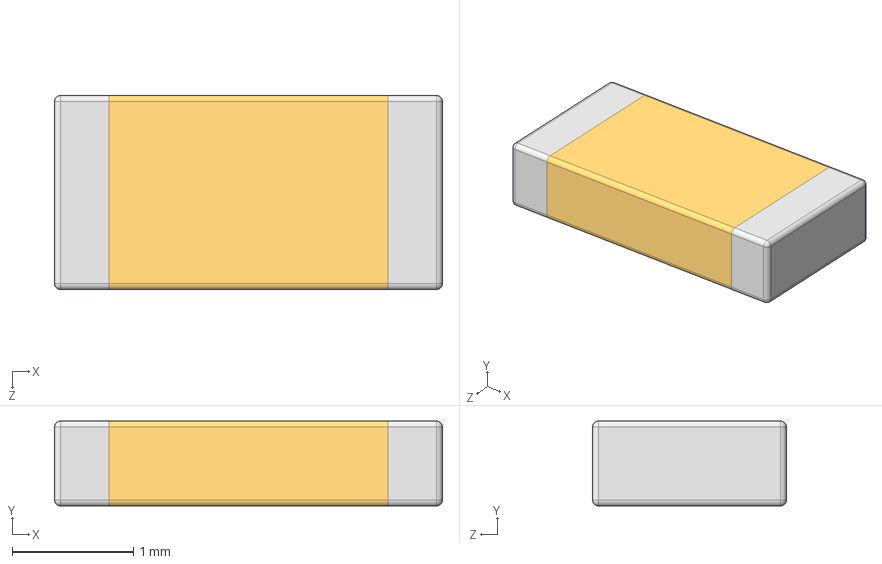
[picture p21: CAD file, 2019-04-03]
Design Documentation/3D Models/CAPC/CAPC3216X70N EIA 1206.step
3.20 x 0.7 x 1.60 mm

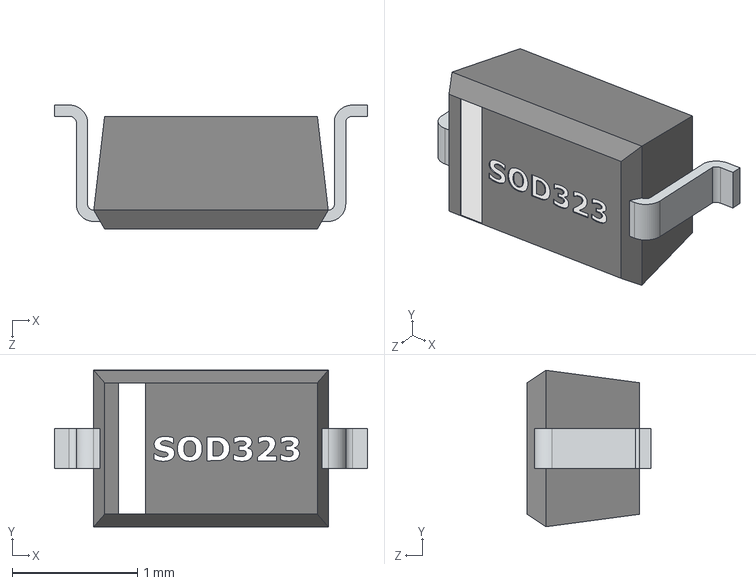
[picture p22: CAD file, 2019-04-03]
Design Documentation/3D Models/User Library-SOD323.step
2.50 x 1.25 x 0.99 mm

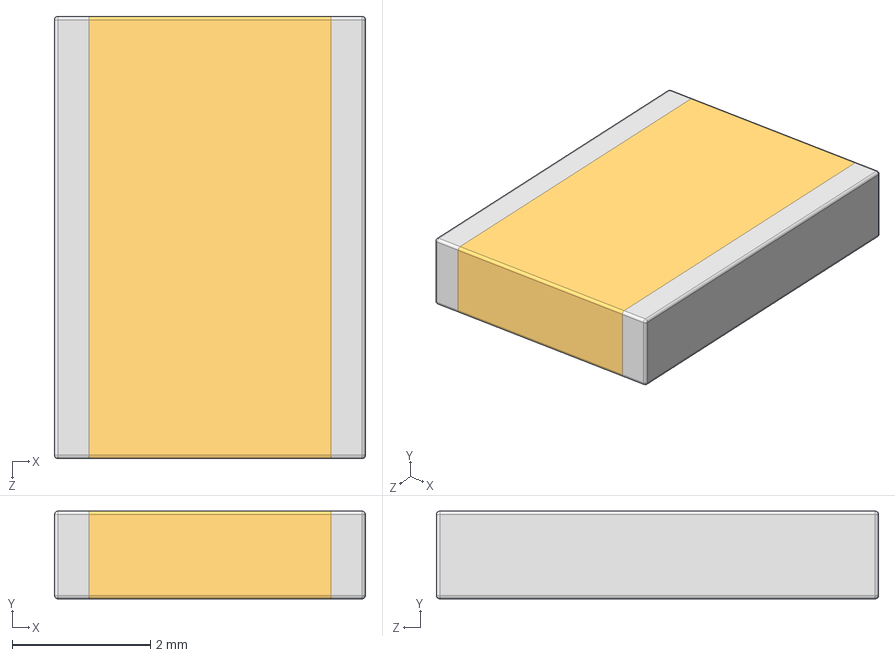
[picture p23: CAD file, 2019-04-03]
Design Documentation/3D Models/CAPC/CAPC4564X127N EIA 1825.step
4.50 x 1.27 x 6.40 mm

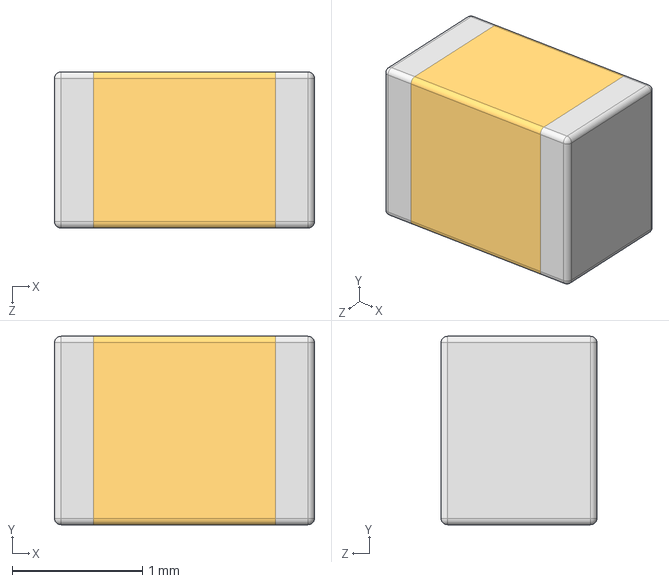
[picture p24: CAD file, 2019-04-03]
Design Documentation/3D Models/CAPC2012X145N EIA 0805.step
2.00 x 1.45 x 1.20 mm

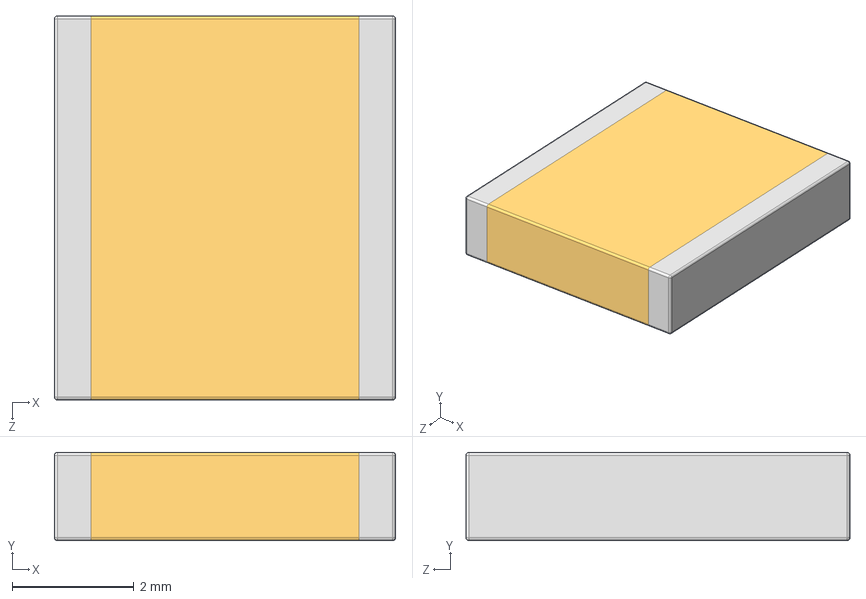
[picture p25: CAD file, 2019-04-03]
Design Documentation/3D Models/CAPC/CAPC5663X145N EIA 2225.step
5.60 x 1.45 x 6.30 mm

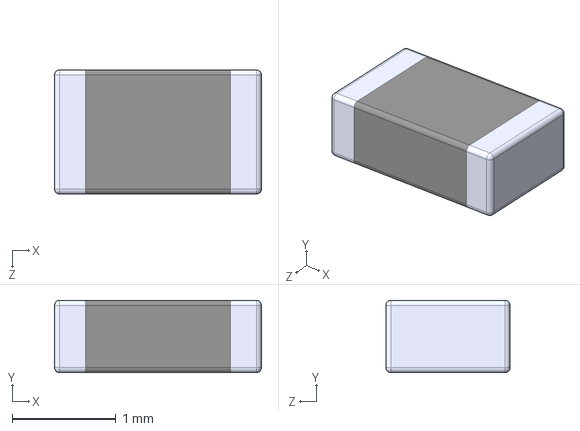
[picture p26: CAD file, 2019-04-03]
Design Documentation/3D Models/User Library-Chip Resistor2.step
2.00 x 0.7 x 1.20 mm

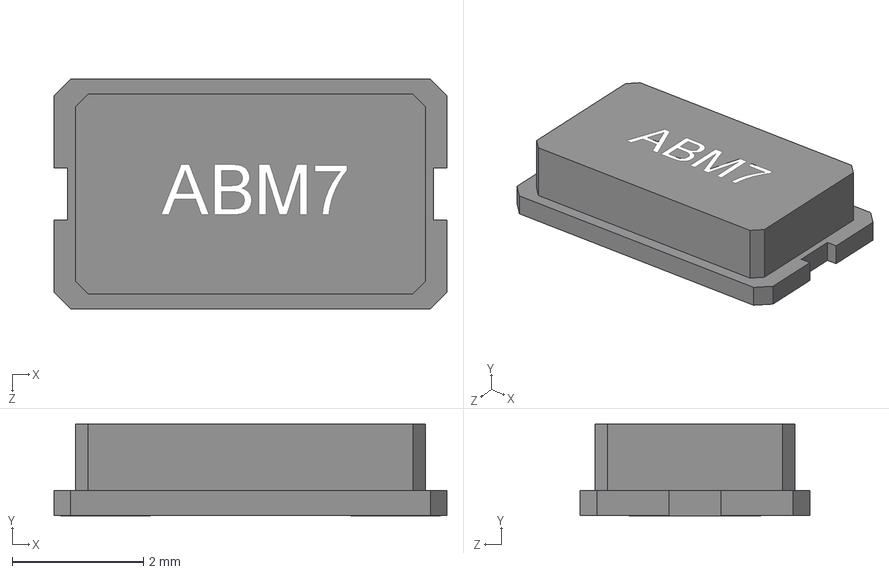
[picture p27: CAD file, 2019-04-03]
Design Documentation/3D Models/ABM7.STEP
5.99 x 1.40 x 3.51 mm

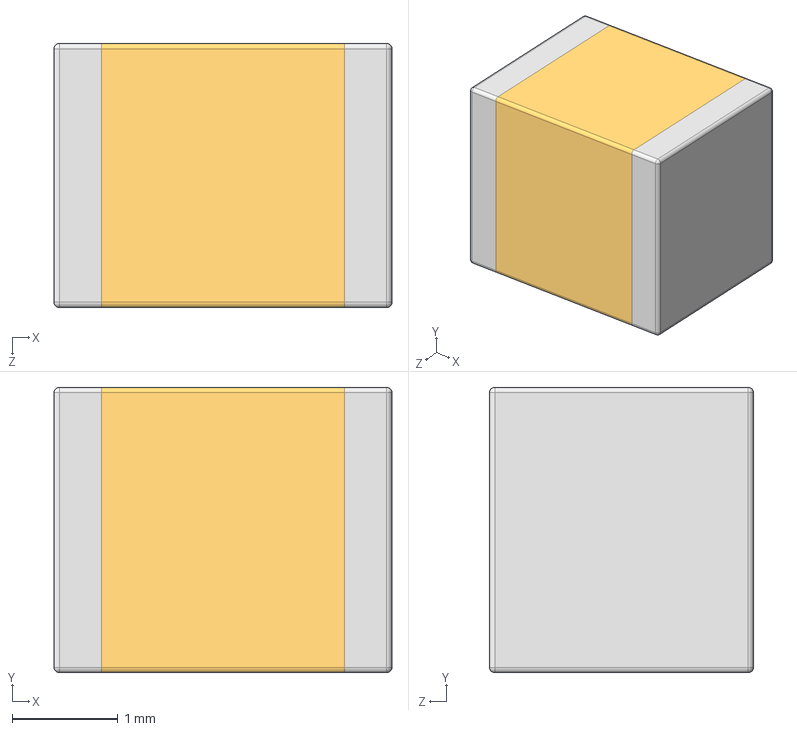
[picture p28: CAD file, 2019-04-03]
Design Documentation/3D Models/CAPC/CAPC3225X270N EIA 1210.step
3.20 x 2.70 x 2.50 mm

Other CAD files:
Design Documentation/3D Models/CAPC/CAPC4564X160N EIA 1825.step
Design Documentation/3D Models/CAPC/CAPC3225X180N EIA 1210.step
Design Documentation/3D Models/CAPC2012X95N EIA 0805.step
Design Documentation/3D Models/CAPC/CAPC4532X140N EIA 1812.step
Design Documentation/3D Models/961204-6404-XX.stp
Design Documentation/3D Models/CAPC/CAPC0603X33N EIA 2220.step
Design Documentation/3D Models/CAPC/CAPC0816X61N EIA 0363.step
Design Documentation/3D Models/CAPC/CAPC1005X55N EIA 0402.step
Design Documentation/3D Models/CAPC/CAPC1005X56N EIA 0402.step
Design Documentation/3D Models/CAPC/CAPC1005X60N EIA 0402.step
Design Documentation/3D Models/CAPC/CAPC1220X107N EIA 0508.step
Design Documentation/3D Models/CAPC/CAPC1320X76N EIA 0508.step
Design Documentation/3D Models/CAPC/CAPC1508X65N EIA 0603.step
Design Documentation/3D Models/CAPC/CAPC1608X55N EIA 0603.step
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

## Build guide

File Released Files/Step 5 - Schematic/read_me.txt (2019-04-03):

Update Schematic Cover Page to RELEASED DD-MMM-YYYY
Place here PDF version of schematic, if possible one for each BOM variant.

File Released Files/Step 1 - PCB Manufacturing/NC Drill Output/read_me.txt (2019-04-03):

Place here drill files and documents which explain it (e.g. for HDI PCB you can put here pdf showing drills for each layer pair)

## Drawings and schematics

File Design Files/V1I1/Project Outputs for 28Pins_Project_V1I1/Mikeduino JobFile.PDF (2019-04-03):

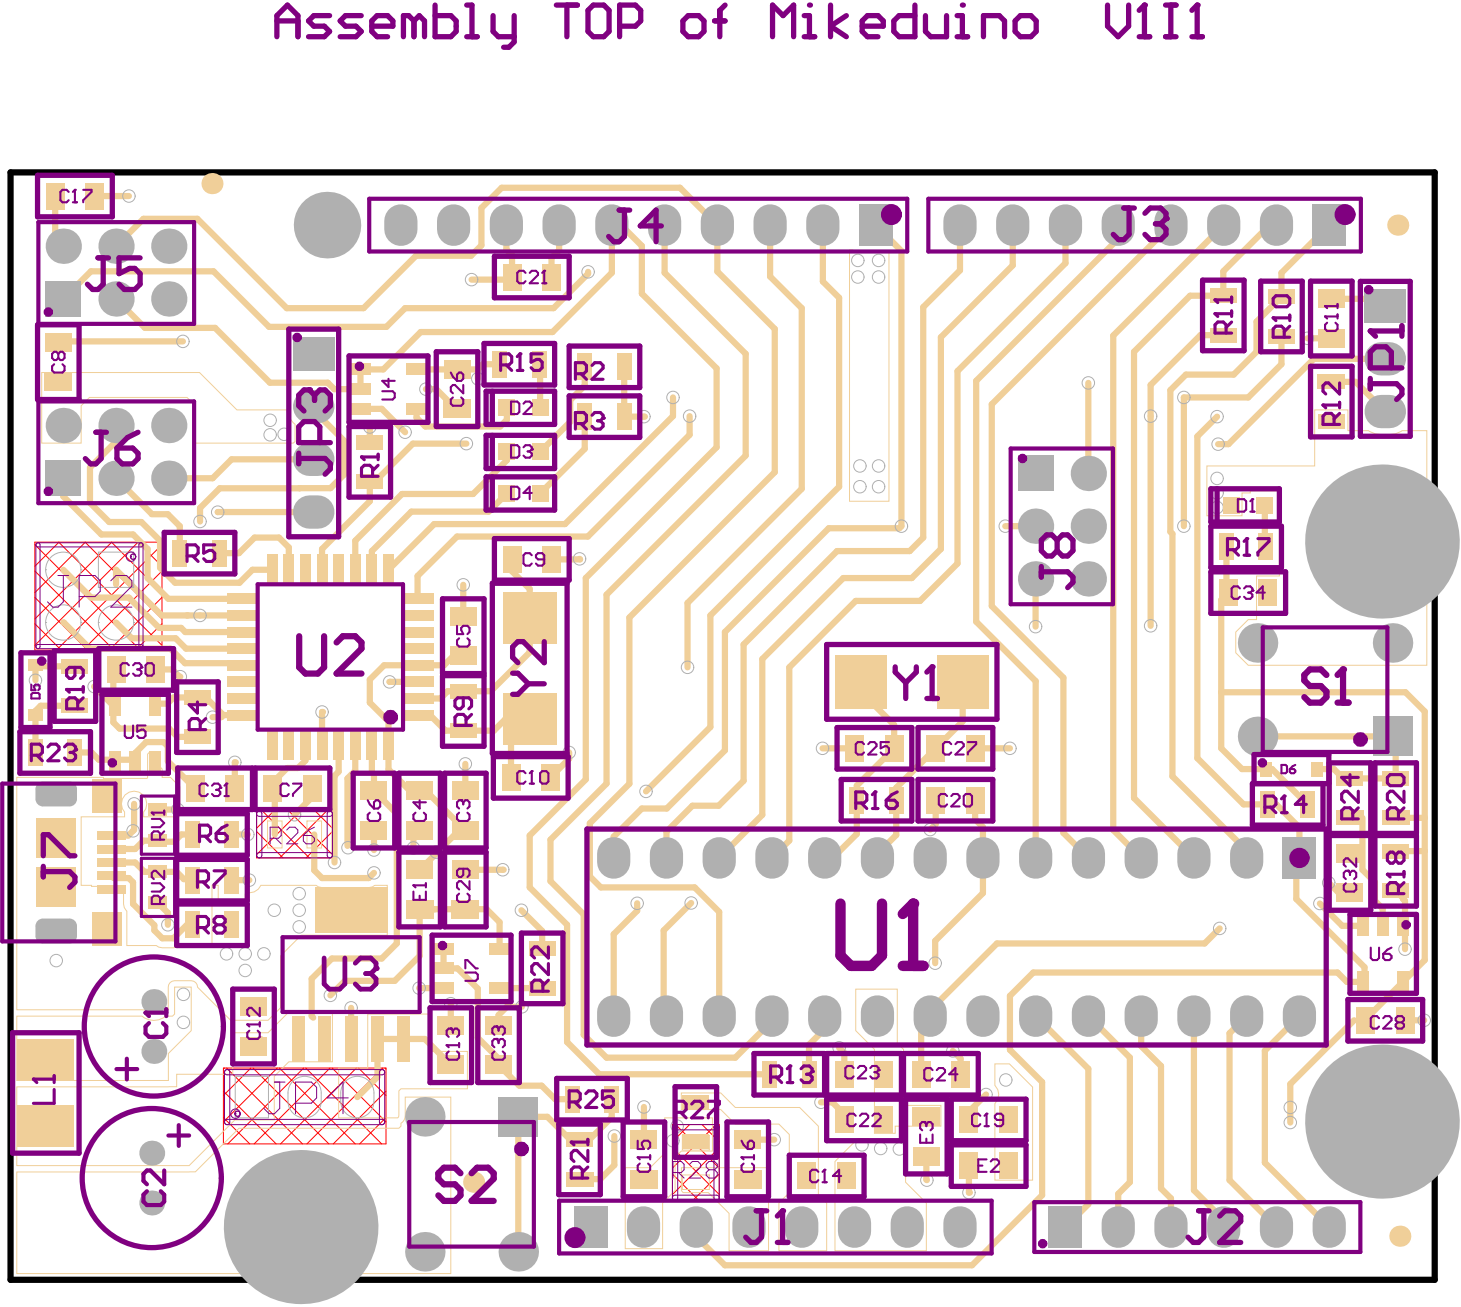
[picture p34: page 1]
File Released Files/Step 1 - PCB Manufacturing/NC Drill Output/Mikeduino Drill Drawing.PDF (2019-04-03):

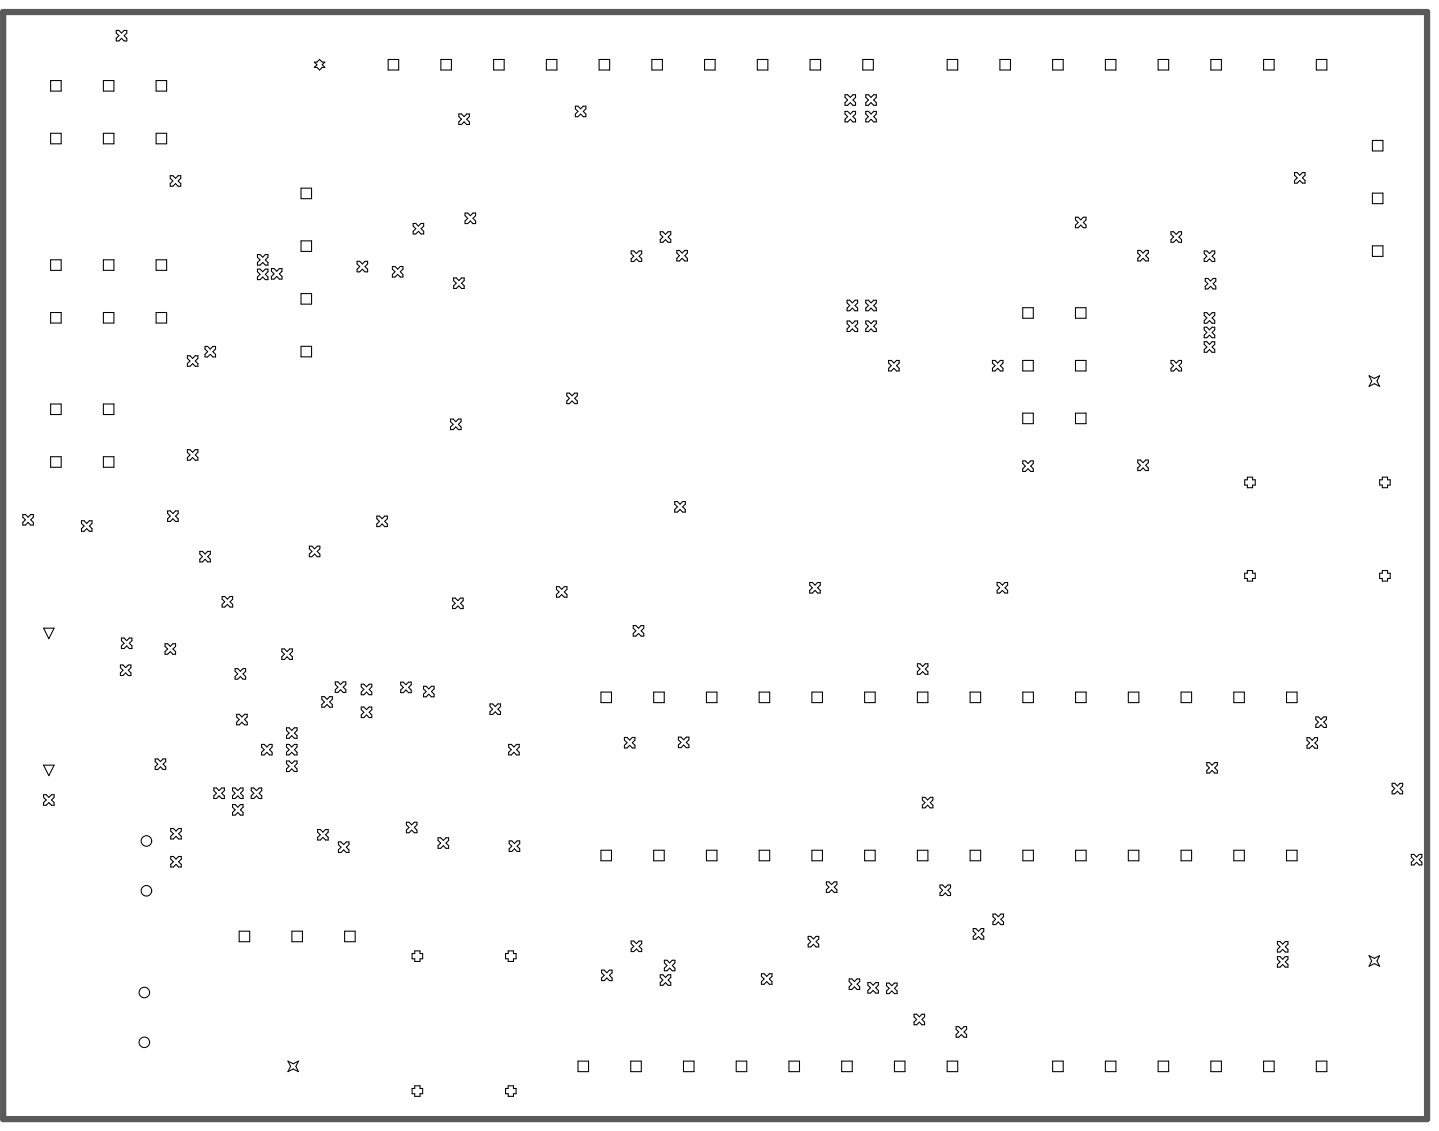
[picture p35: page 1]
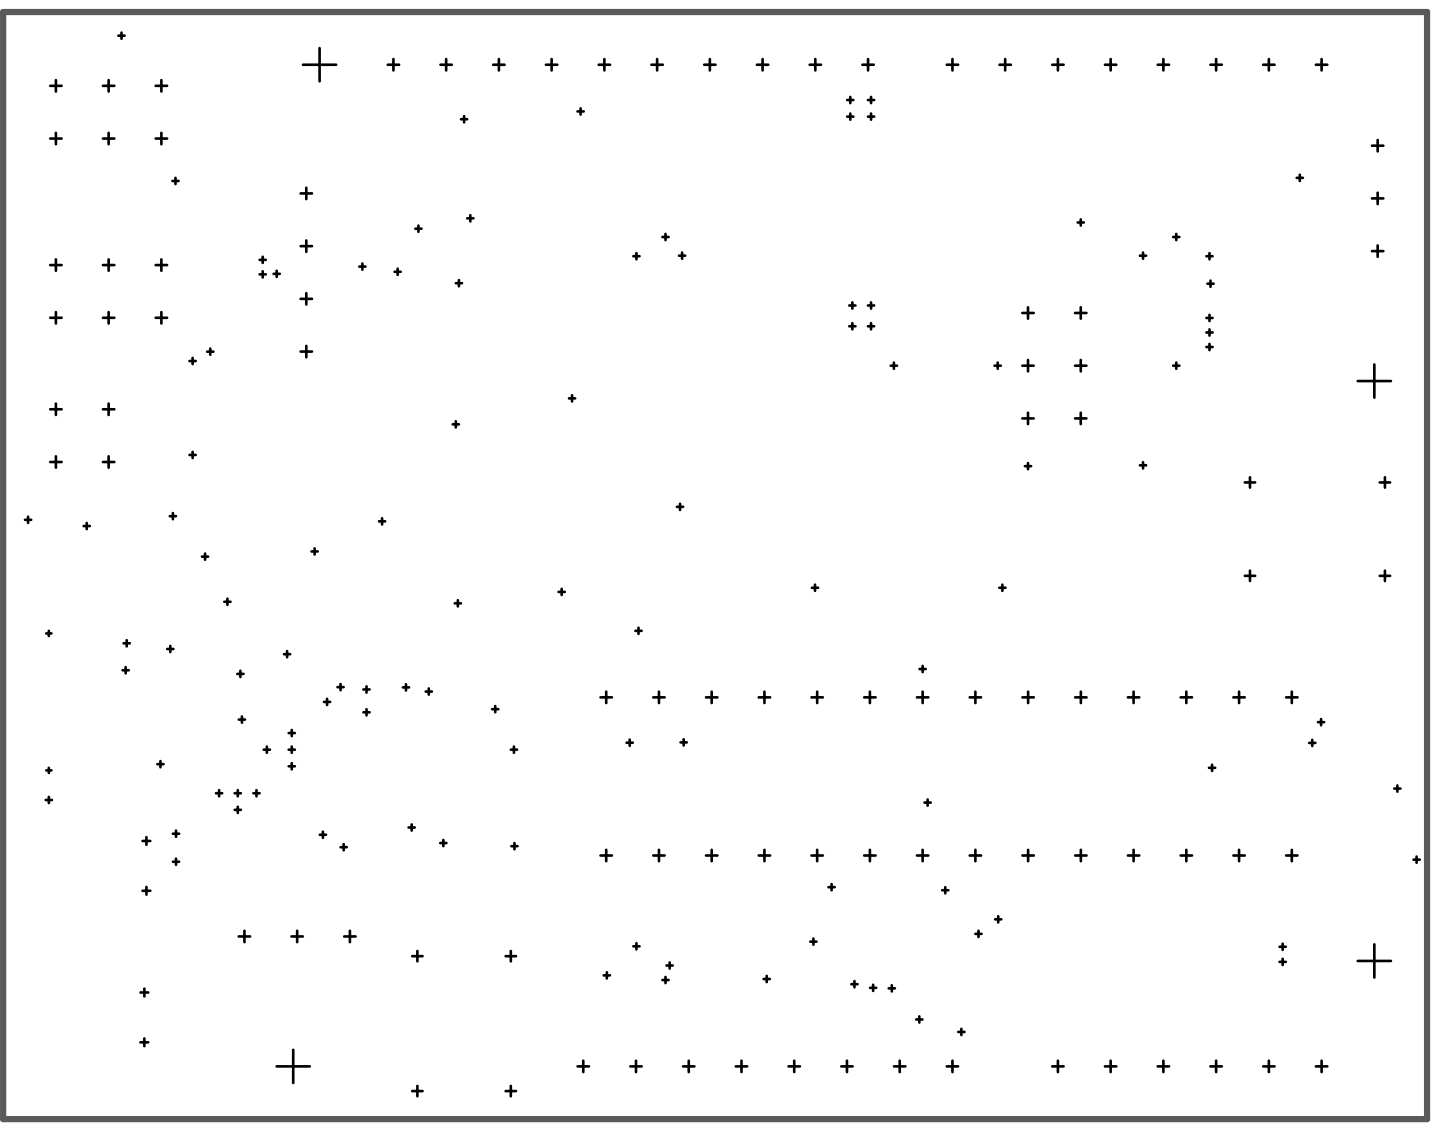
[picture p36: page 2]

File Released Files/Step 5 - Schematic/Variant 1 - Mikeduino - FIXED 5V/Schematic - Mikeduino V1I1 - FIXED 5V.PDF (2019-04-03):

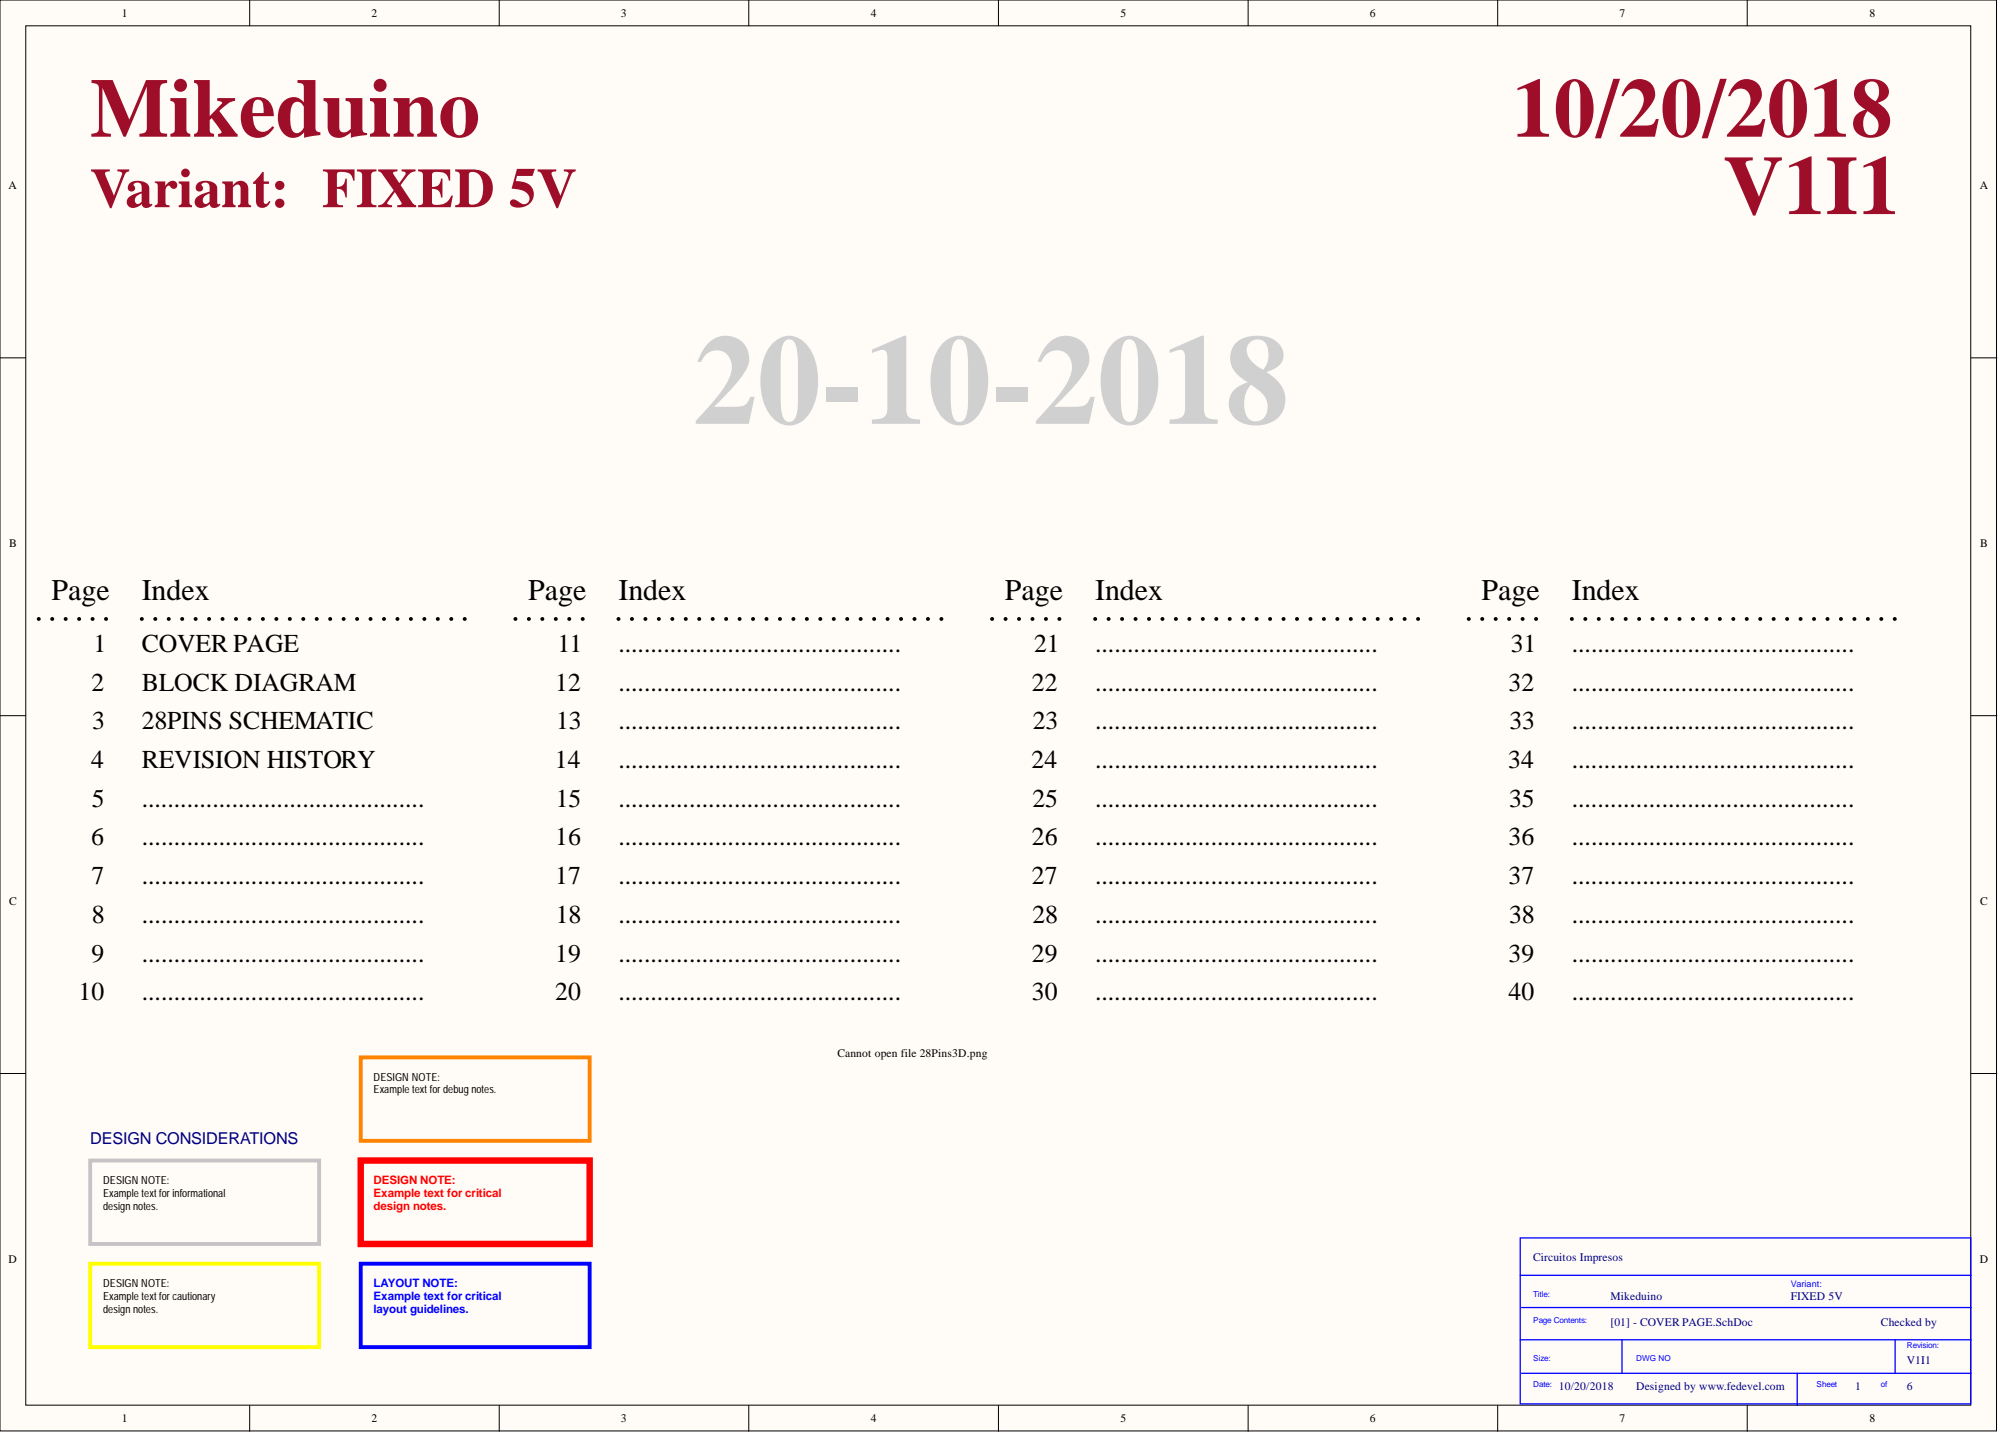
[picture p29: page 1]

Cannot open file 28Pins3D.png

DESIGN NOTE:
Example text for debug notes.

Example text for informational
design notes.

Example text for critical

Example text for cautionary

LAYOUT NOTE:
layout guidelines.

Size: | DWG NO | Revision: V1I1

Date: 10/20/2018 Designed by www.fedevel.com | Sheet of

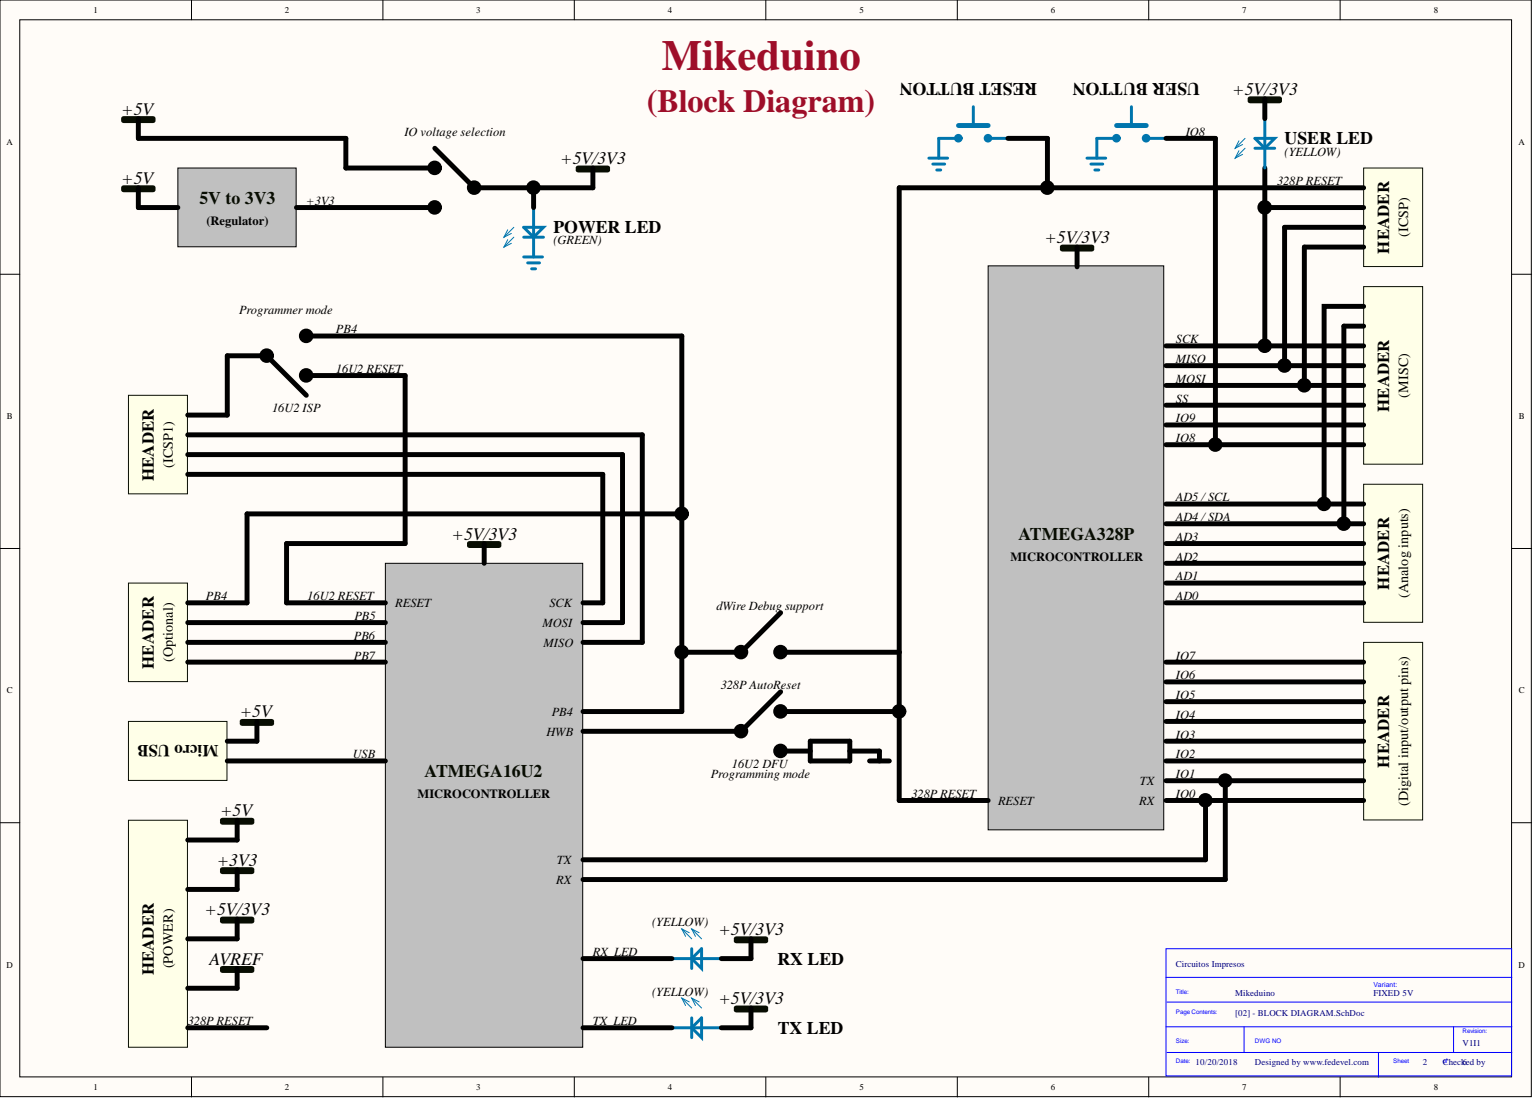
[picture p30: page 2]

MISO
MOSI
SS
IO9
IO8

AD5 / SCL
AD4 / SDA

(Digital input/output pins)

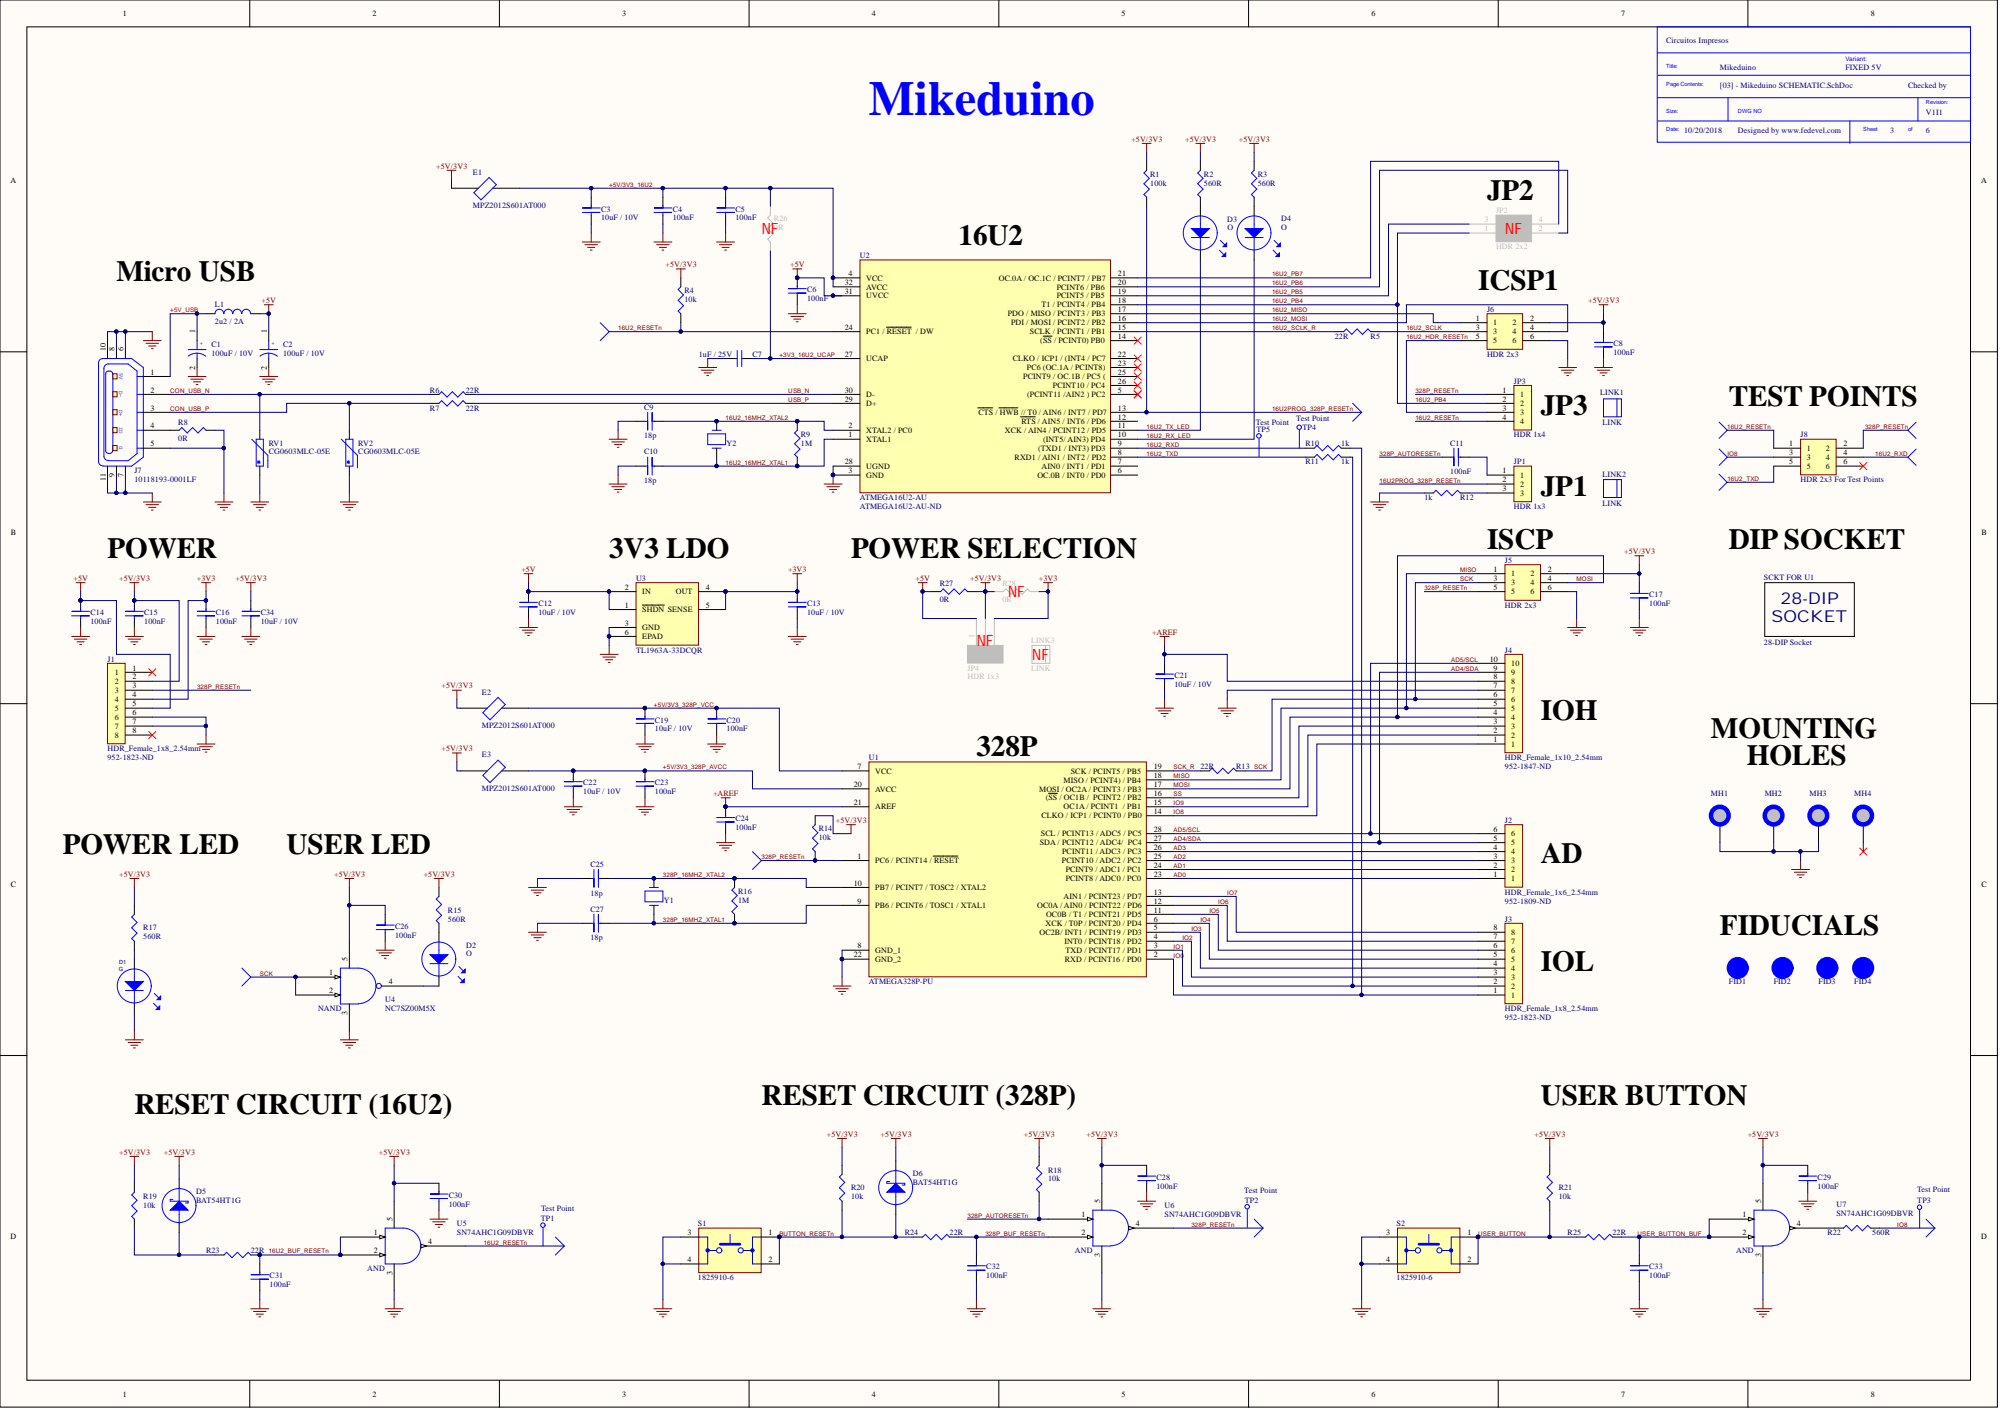
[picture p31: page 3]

16U2_PB4
16U2_MISO | | J6
16U2_MOSI

16U2_SCLK

HDR 2x3 For Test Points

AREF 21 | | SS

PC6 / PCINT14 / RESET 1 | | IO8

PB7 / PCINT7 / TOSC2 / XTAL2 10 | AD1

IO7
IO1 | | 1 1 2 2 3 3 4 4 5 5 6 6 7 7 8 8
IO2

GND_1 8 | IO5

GND_2 22 | IO0

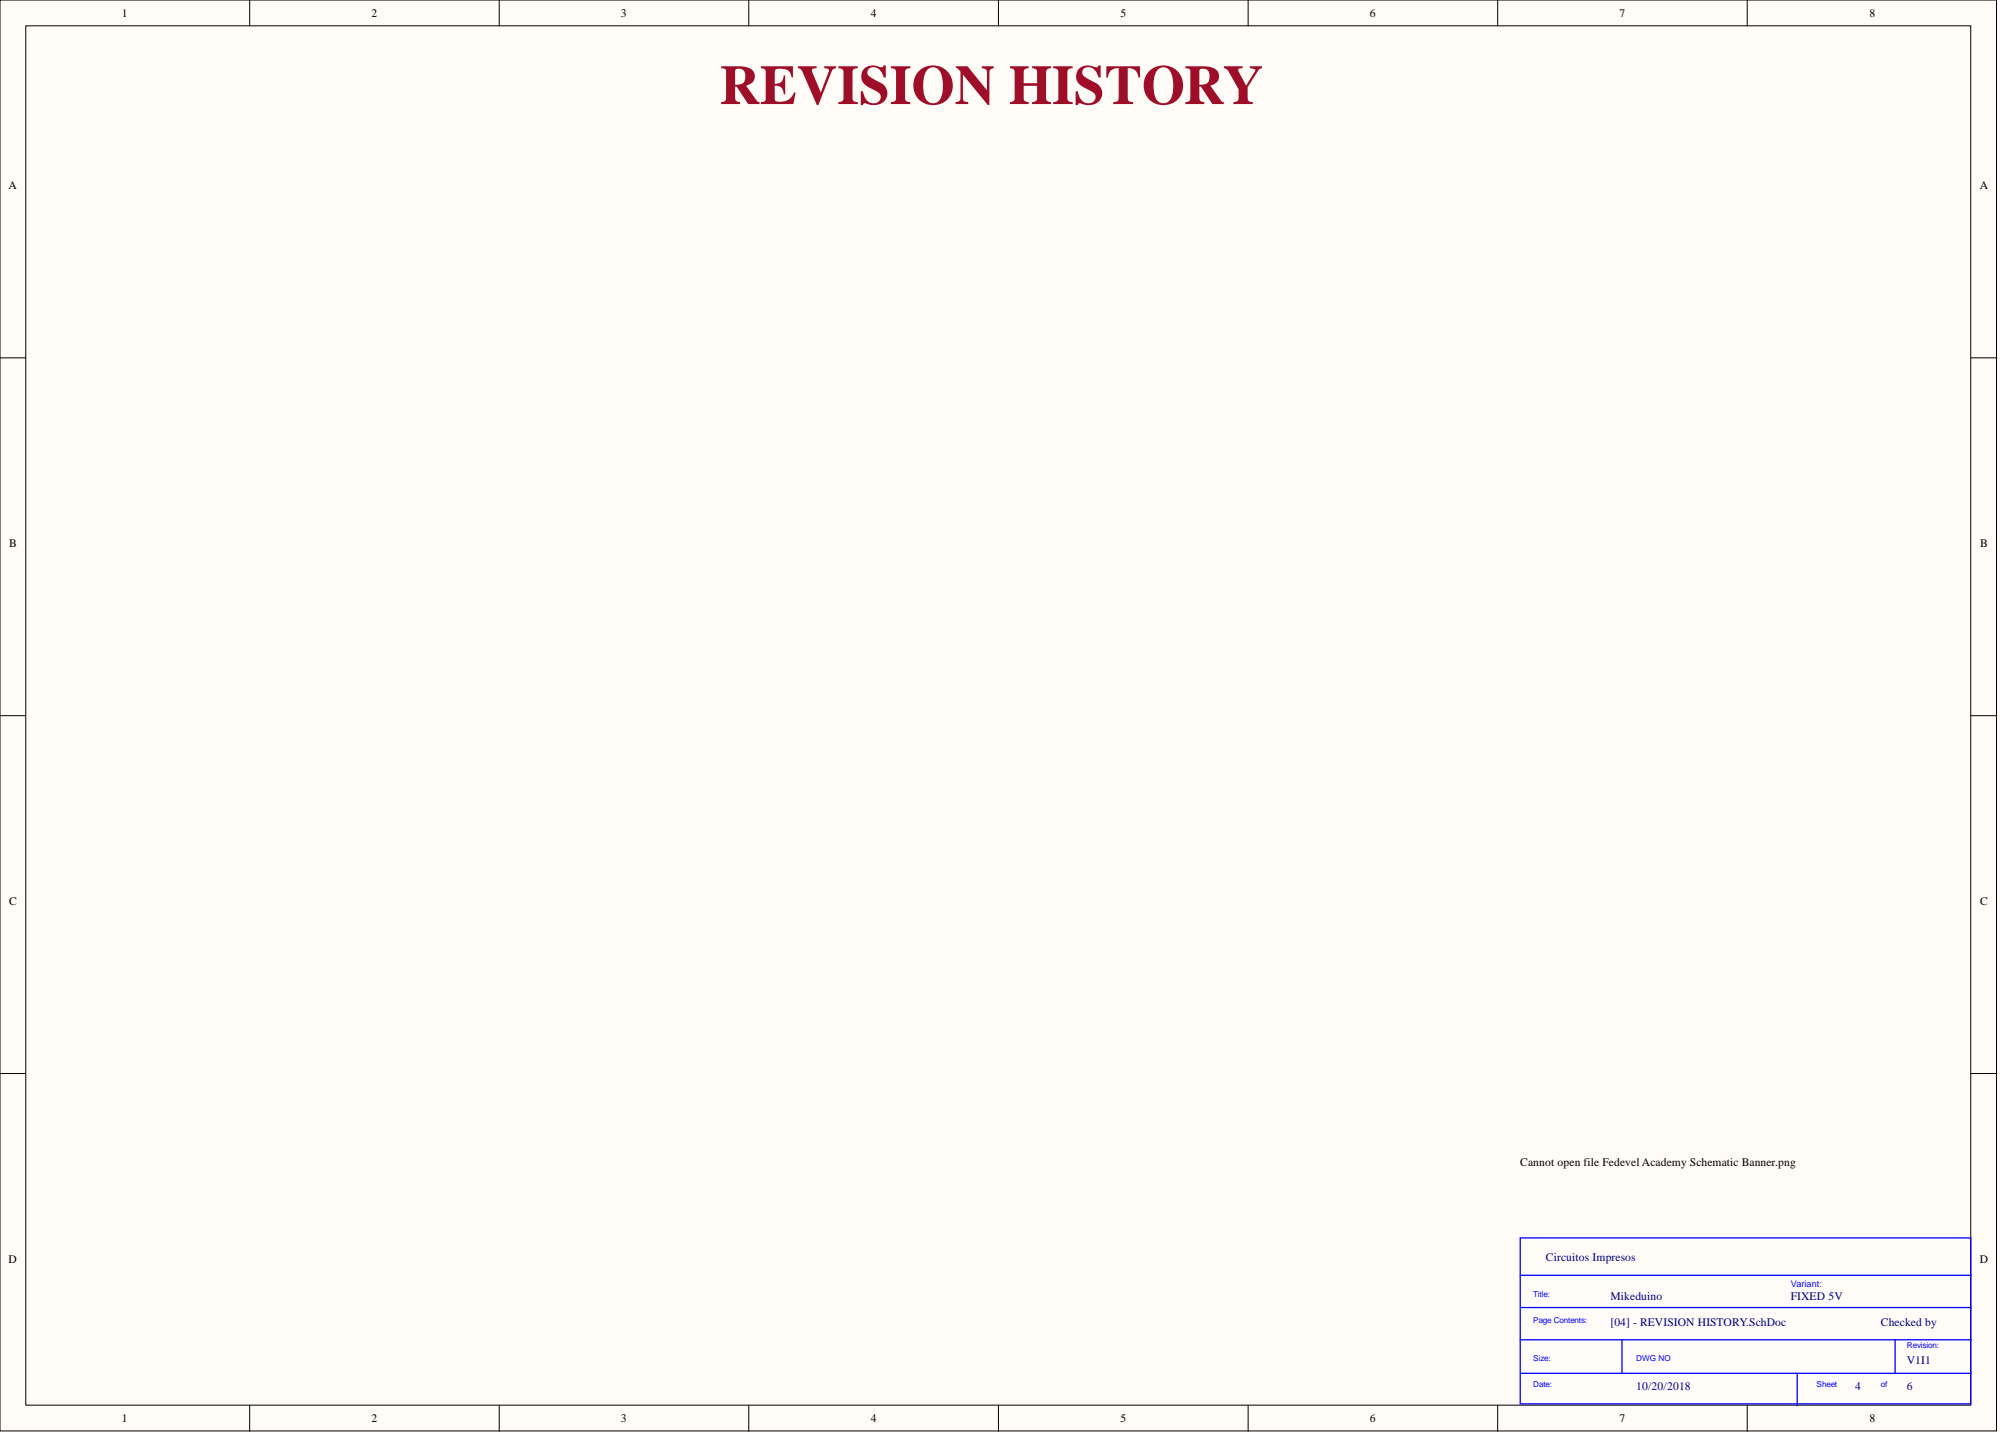
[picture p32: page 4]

Cannot open file Fedevel Academy Schematic Banner.png

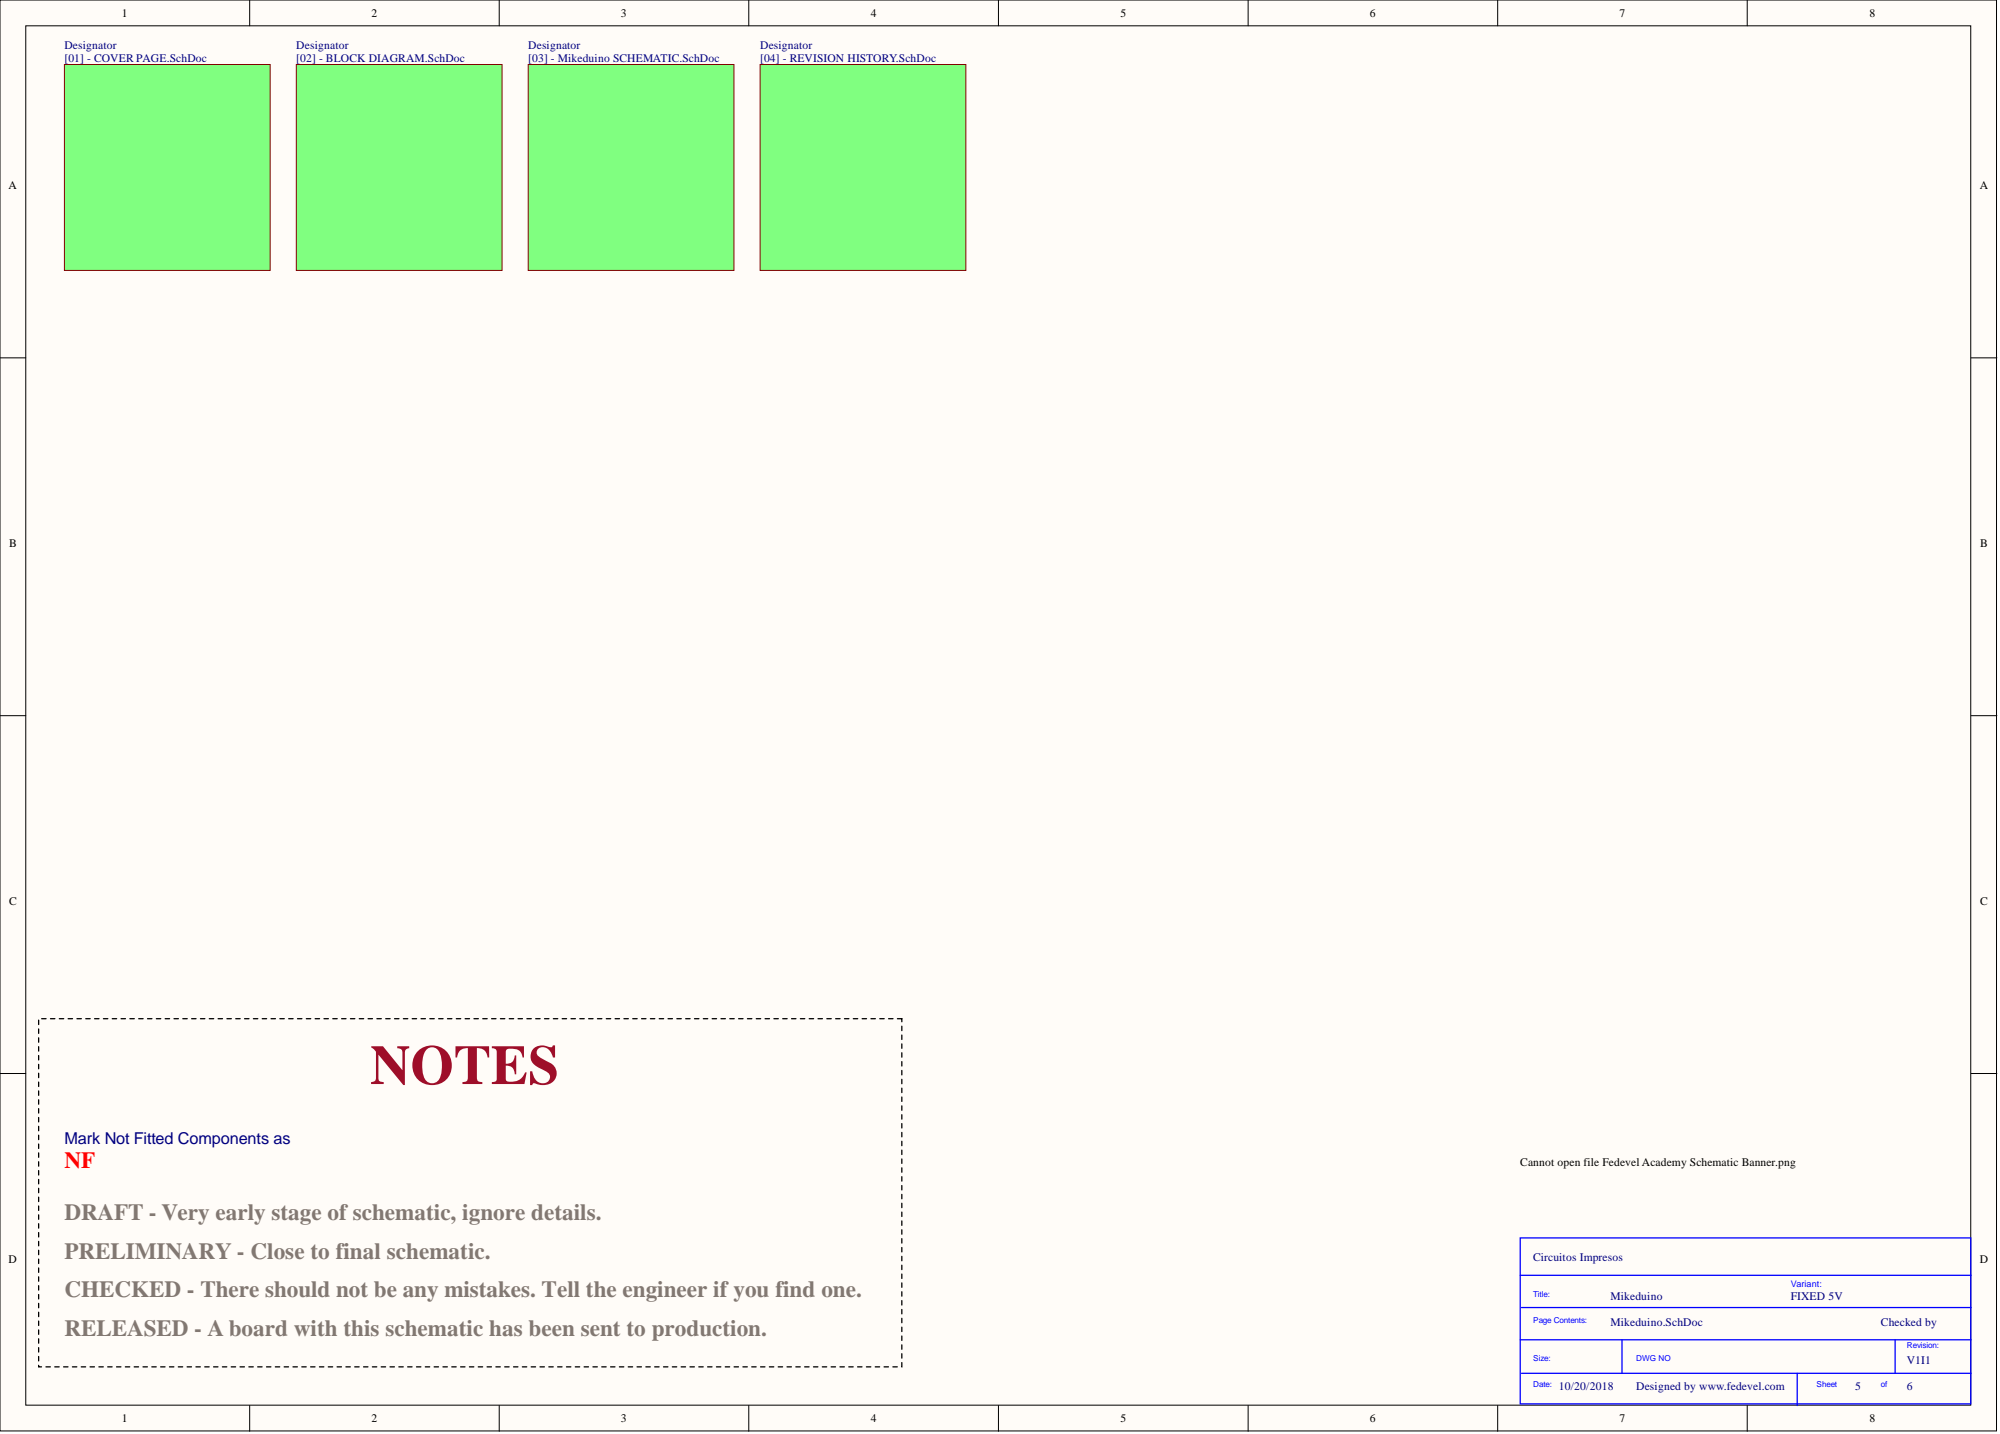
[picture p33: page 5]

Mark Not Fitted Components as

Cannot open file Fedevel Academy Schematic Banner.png

DRAFT - Very early stage of schematic, ignore details.
PRELIMINARY - Close to final schematic.
CHECKED - There should not be any mistakes. Tell the engineer if you find one.
RELEASED - A board with this schematic has been sent to production.

Designed by www.fedevel.com
